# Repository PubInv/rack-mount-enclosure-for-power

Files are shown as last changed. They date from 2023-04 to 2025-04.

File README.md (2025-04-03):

# OEDCS
Oxygen Engine Digital Control System, enclosure for.

## As of 2024 the Enclosure has Evolved to a 3U rack mount
Simplified view of enclosure before connector and other holes added.


Exploded view of enclosure parts and the "Plant Panel" too


## Notes on BIG Enclosure Unit Fabrication of Spring 2023
* Serial number 1  AKA the Austin Unit.
LAN TYPE: SEEEDS STUDIO W5200
MAC Address: FE:ED:1B:70:08:77  
See images in folder at: https://github.com/PubInv/NASA-COG/tree/develop/docs/OEDCS_June_2023_Version_0.1/Photos
This is the Control V1.0 board. Taken out of service at Austin on about ?20240215?  
Control V1.1 SN 09 installed on 20240220. See its MAC below.

* Serial number 2  
  
LAN TYPE: ????
MAC Address: FE:ED:10:69:73:70  
This is the Control V1.0 board. Taken out of service at AmOx on about 20240220  
Control V1.1 SN 12 installed on 20240220. See its MAC below

* Stage II controler  
  
LAN TYPE: ????
MAC Address: FE:ED:14:71:02:77  
ID = 1361064480,1313945940,842021169,959459378

* Serial Number 9  
LAN TYPE: ARDUINO  
MAC Address: FE:ED:1D:70:05:6D
Control V1.1 SN 09 installed on OEDCS SN1 about ?20240215? 

* Serial Number 10  
LAN TYPE: ARDUINO  
MAC Address: FE:ED:12:71:06:65
Control V1.1 in Austin as of about Feb 2024.

* Serial Number 11 Formerly the Mockup Of Maryville
LAN TYPE: SEEEDS STUDIO W5200
  
MAC Address: FE:ED:16:6B:72:67

* Serial Number 12
LAN TYPE: ARDUINO  
MAC Address: FE:ED:17:73:0E:69
Located at AmOx as of about 20240220 in OEDCS SN2.

* Serial Number 13  
LAN TYPE: ARDUINO 
MAC Address: FE:ED:1A:71:09:7F
Control V1.1 in Oklahoa City as of about ?January 2024.?

## Mechanical Files

* The "frontpanel" folder has FreeCAD drawing which generate the DXF and other files for fabrication of the frontpanel, bottompanel and rear panel.
* The "enclosure" folder has an OpenSCAD drawing of the Unit 1 enclosure. With in the folder is a folder "FreeCADAssy" which has a FreeCAD drawing using the A2plus work bench and duplicates roughly the Unit 1 assembly but which has the Unit 2 frontpanel, bottompanel and rear panel files.

## Front Panel and Enclosure Folders  Unit 2
Place holder for July-August 2023 Begin Construction of Unit 2. 

* Fabrication of Version 2 unit Frontpanel, Bottompanel and Rearpanel not by hand in house. ** DONE!**  
* The Frontpanel Version 2 has enlarged AC receiptical opehnings and will require reciptical cover plates.  **DONE!**  

## Front Panel and Enclosure Folders  Unit 1
A March 2023 enclosure for prototyping, proof of concept for the COG controller. 
This prototype has:
* A programmable power supply (Voltage and current). Power Electrinics, TF800K12A. URL: https://slpower.com/downloads-and-tech-support
* Solid state relays for switching AC power to preheaters. Sparkfun # COM-13015. URL: https://www.sparkfun.com/products/13015  
* Power and PWM control for fans to force air into the COG
* Air Temperature: Adafruit MAX31850 amplifier assemblies. Adafruit Product ID: 1727. URL: https://www.adafruit.com/product/1727
* Air flow rate sensors  NOT MOUNTED
* An Arduino Due for system control.
Navigate into the folders to see more.

Overhead view of Unit 1 wiring as of June - July 2023

https://user-images.githubusercontent.com/5836181/250552512-68546480-32a5-4593-8a75-600ff2462f9f.png

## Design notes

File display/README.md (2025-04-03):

# 3U Enclosure, Display, 
Enclosure for an I2C OLED 2.4" Display and a Rotary Encoder 

## Mechanical Files
File name: OLED_2.4inchHiLetGo.FCStd


### Drawings for LCD, I2C
2.4" OLED Made scaled model from image. Used FreeCAD.


### Drawings for Rotary Encoder with Switch assembly
3D file from: https://grabcad.com/library/rotary-encoder-arduino-daughter-board-1


## Notes on Unit Fabrication
The horizontal hole spacing is same as the 3U rack mount enclosure. I began thinking it might surface mount but think it improble.

## Notes

## Firmware Files
Folder Due_BOOTUP_OLED containes Arduino IDE code for a Due which workes with an OLED on the I2C zero port, pins D20 and D21.

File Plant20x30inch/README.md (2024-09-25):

# Plant Assembly 



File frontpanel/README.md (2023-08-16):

# Frontpanel
An aluminum plate on which the NASA-COG control system electrical intefaces are mounted from, and presented to the controlled elements.
This front panel was later mounted to an enclosure defined in the enclosure folder.

## Details
Developed in FreeCAD
One FreeCAD drawing defins the **Frontpanel**, **Rearpanel** and **Bottompanel**. There is a drawing representing two DIN rails that may be mounted on the bottom panel.
Images of many parts to be mounted on the front panel are scaled and place in a group. This group can be displayed on the front panel to check the design and convey the resulting device.

## Second Front Panel Fabrication Notes
Fabrication of a Second controler beginning late July 2023.
Version 2 front panel.
FreeCAD view


Fabrication drawing for front panel Version 2.0 of 20230731


## Parts List Second Controller (Partial)
| Quantity 	| Description 	| Manufacturer 	| Man Part Number 	| Distributor 	| Distributor Part Number 	| Drawing 	| Cost Each 	|
|---	|---	|---	|---	|---	|---	|---	|---	|
| 1 	| frontpanel-PartFrontPanel2frontpanel2.dxf 	| PublicInvention 	| TBD 	| NA 	| NA 	| [frontpanel-PartFrontPanel2frontpanel2.dxf](frontpanel-PartFrontPanel2frontpanel2.dxf) 	| 	|

<hr> 

## First Front Panel Fabrication Notes
Fabrication drawing for front panel of 20230324


## Parts List (Partial)

| Quantity | Description | Manufacturer | Man Part Number | Distributor | Distributor Part Number | Drawing | Cost Each |
|---|---|---|---|---|---|---|---|
| 1 | frontpanel_Rev1_3.dxf | PublicInvention | TBD | NA | NA | [frontpanel_Rev1_3.dxf](frontpanel_Rev1_3.dxf) | |
| 3 | Panel Plate SB1 Dual | | | Powerwerx | PanelPlateSBDual | [SB1 Drawing](Parts/Mech/PanelplateSB1-SB1DuaulDimensions.pdf) | 14.99 |
| 6 | Protective Plug with Lanyard | | | Powerwerx | PLUG-SB50 | https://powerwerx.com/rigid-plug-cap-lanyard-sb50 | 4.49 |
| 3 | Circuit Breaker | Carling Technologies | AA1-B0-34-615 -5D1-C | Granger | 10C591 | [Breaker Drawing](Parts/Mech/Breaker_10C588_1.pdf) | 14.77 |
| 3 | GFI Receptical | | | Harbor Freight | 57958 | https://www.harborfreight.com/15-amp-125v-self-test-gfci-duplex-outlet-57958.html | 9.99 |
| 1 | DB25 Panel Mount, FanControllerBareBoardPCB  | PublicInvention | TBD | | | [FanControllerBareBoardPCB.jpg](../develop/elec/FanControllerBareBoardPCB.jpg) | |
| 1 | DB9 Panel Mount, I2C interface | PublicInvention | TBD | | | | |
| 1 | ground bar | GE | TGK12CP | Lowes | 105748 | https://www.lowes.com/pd/GE-1-in-Ground-Bar-Kit/1001535 | $8.98 |
| 1 | Jack Panel for Thermocouple 1x12 | Omega | MJP1-12-BLANK | Omega | MJP1-12-BLANK | [Jack Panel Drawing](Parts/Mech/mpj-j-f-thermocouple/JackPanel_MJP.pdf) | $26.76 |
| 1 | Snap Strip for Thermocouple  1x12 | Omega | MMS-12 | Omega | MSS-12 | [SnapStrip Drawing](Parts/Mech/MSS_Series.pdf) | 12.34 |
| 3 | Miniature Thermocouple Panel Jack Connectors | Omega | MPJ-K-F | Omega | MPJ-K-F | [SnapStrip Drawing](Parts/Mech/MSS_Series.pdf) | $4.26 |
| 24 | M5-8mm pan head screw | | | Amazon | | https://www.amazon.com/M5-0-8-Button-Socket-Stainless-Quantity/dp/B084MMND2L/ref=asc_df_B084MMND2L | $.0899 |
| 24 | 5mm T Nut Sliding 10mmx6mm | | | Amazon | | https://www.amazon.com/Fastener-Nickel-Plated-Sliding-Aluminum-Profile/dp/B086MKNYDS/ref=sr_1_1_sspa | $0.053 |

### Some deviations of note:
I drilled and tapped the holes for mounting the GFI receipticals for 6-32 screw holes and screwed the GFI from the rear with shortened screws. The protuding ends of these screews are a minor hazard for scratching flesh.  
I drilled and tapped the screw holes for 10-32 for mounting the ground bar.
I attached a single teathered connector cap for the Anderson connector with a plastic cable clamp to a near by screw mounting the circuit breaker.  

?April 2023? Robert relocated the ground lug terminal strip inside the cabnet. Lee believes new holes had to be drilled.

## Older FreeCAD screen capture showing images of some of the parts behind the "frontpanel".  
These drawings and ideas lead up to the first fabricated front panel and differ from it.  
Images as of 20230317 2107 EDT




### Cautions
There appears to be an error on the holes for the Anderson front panel connector mount. (20230326 FLE, Corrected before fabrication.)

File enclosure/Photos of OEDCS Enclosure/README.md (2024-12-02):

# 3U OEDCS Assembled
Photos of the October 2024 build of five OEDCS final assemblies.  
Front panels are REV1 which required extensive nibbeling of the SB50 flange.  

<a
href="FrontPanel.JPG">
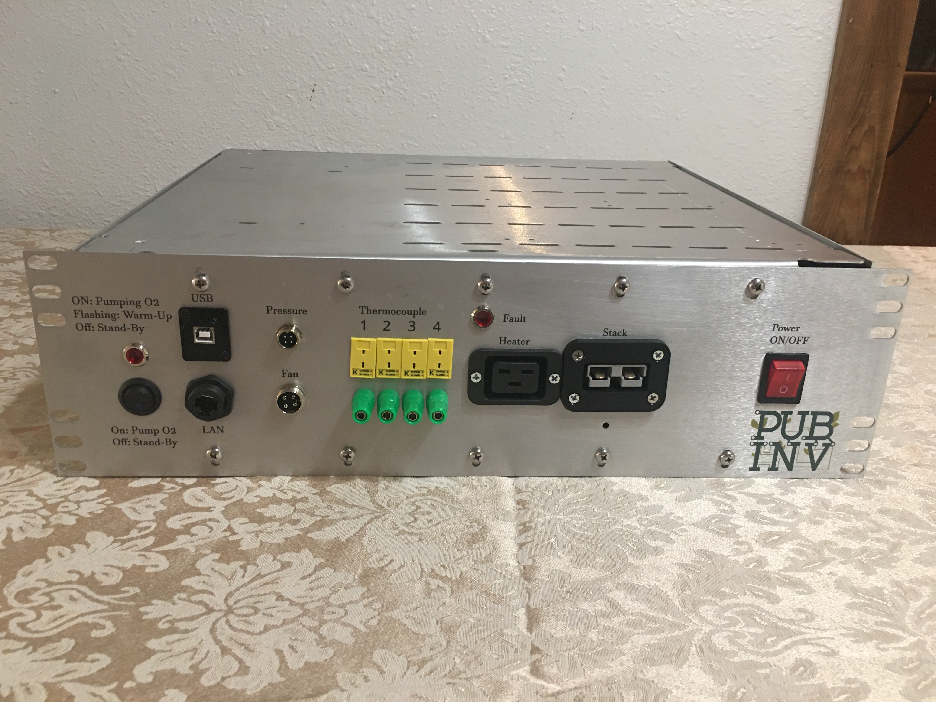
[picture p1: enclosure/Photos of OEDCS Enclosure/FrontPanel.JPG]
  
Front view as assemblied. Click to enlarge </a>

<a
href="Back.JPGg">
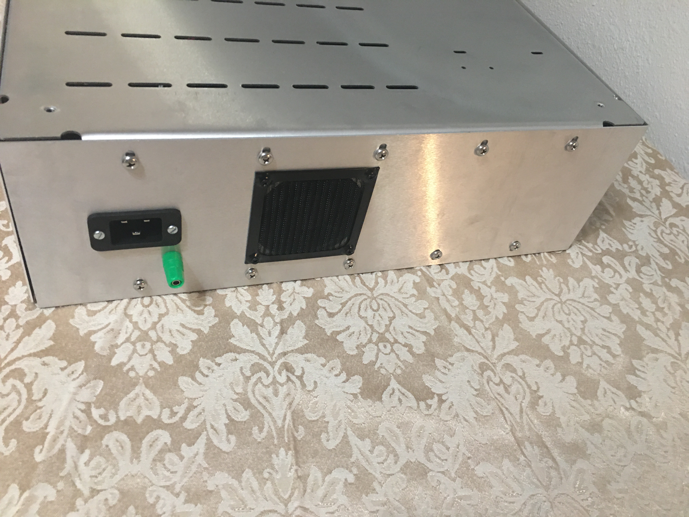
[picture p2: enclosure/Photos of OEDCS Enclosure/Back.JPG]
Back.JPGg
  
Back view as assemblied. Click to enlarge </a>

<a
href="CablesInPlace.JPG">
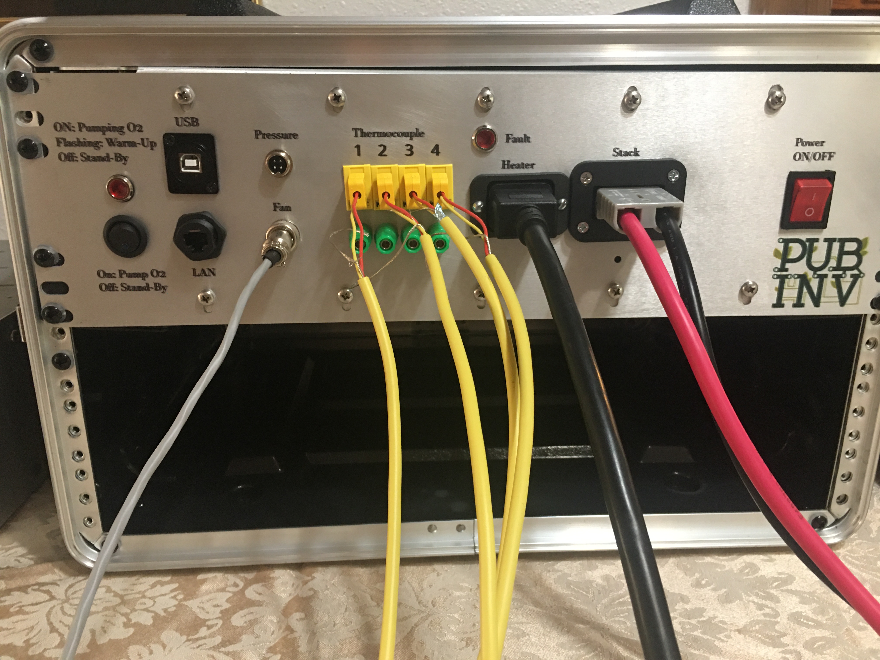
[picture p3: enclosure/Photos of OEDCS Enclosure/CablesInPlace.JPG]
CablesInPlace.JPGG
  
Front view wtih cables. Click to enlarge </a>

<a
href="FrontFromTop.JPG">
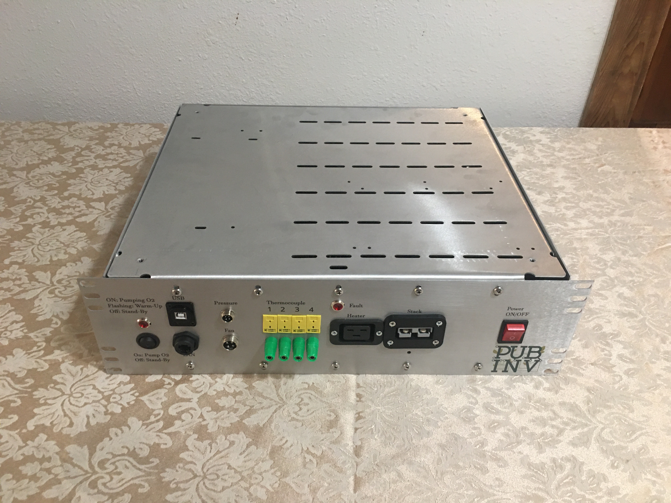
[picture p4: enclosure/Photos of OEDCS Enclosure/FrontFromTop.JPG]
  
Front from top view as assemblied. Click to enlarge </a>

<a
href="Oblique.JPG">
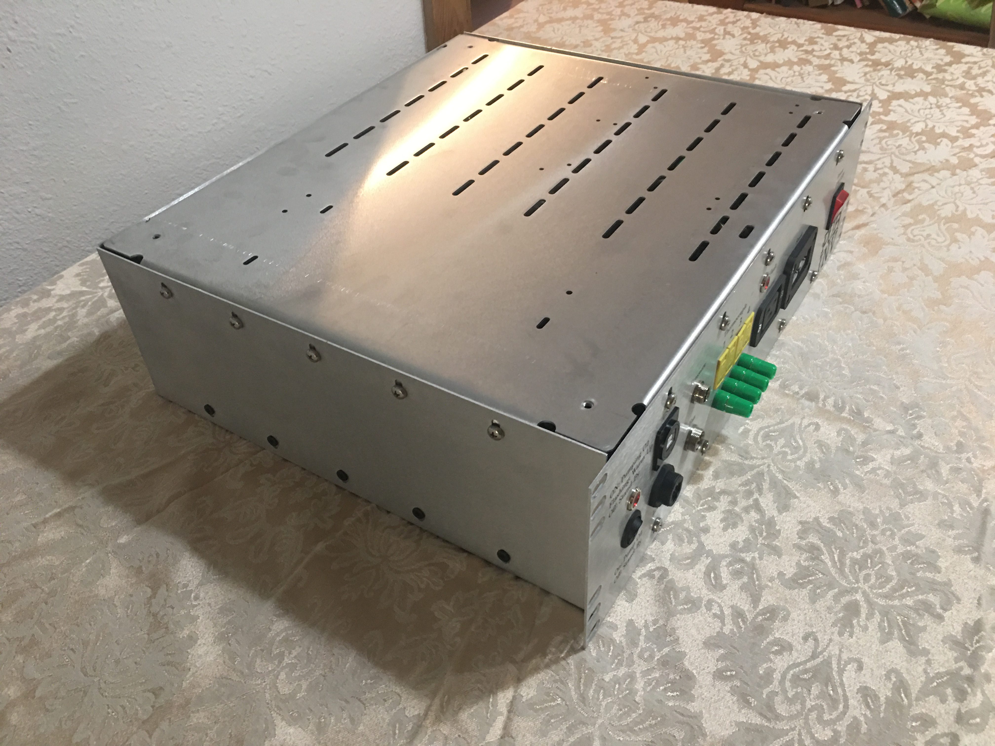
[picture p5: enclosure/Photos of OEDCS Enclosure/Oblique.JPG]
  
Oblique view as assemblied. Click to enlarge </a>

<a
href="Top.JPG">
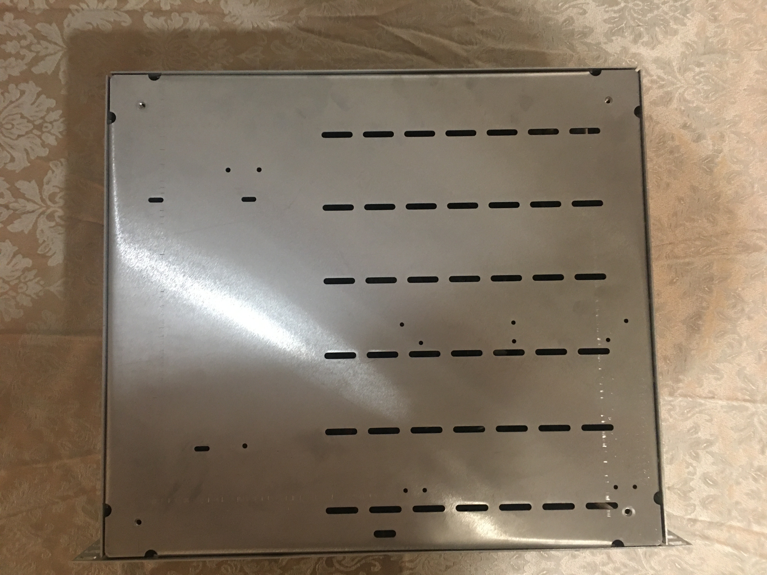
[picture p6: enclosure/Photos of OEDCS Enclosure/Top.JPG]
  
Top view as assemblied. Click to enlarge </a>

<a
href="TopOblique.JPG">
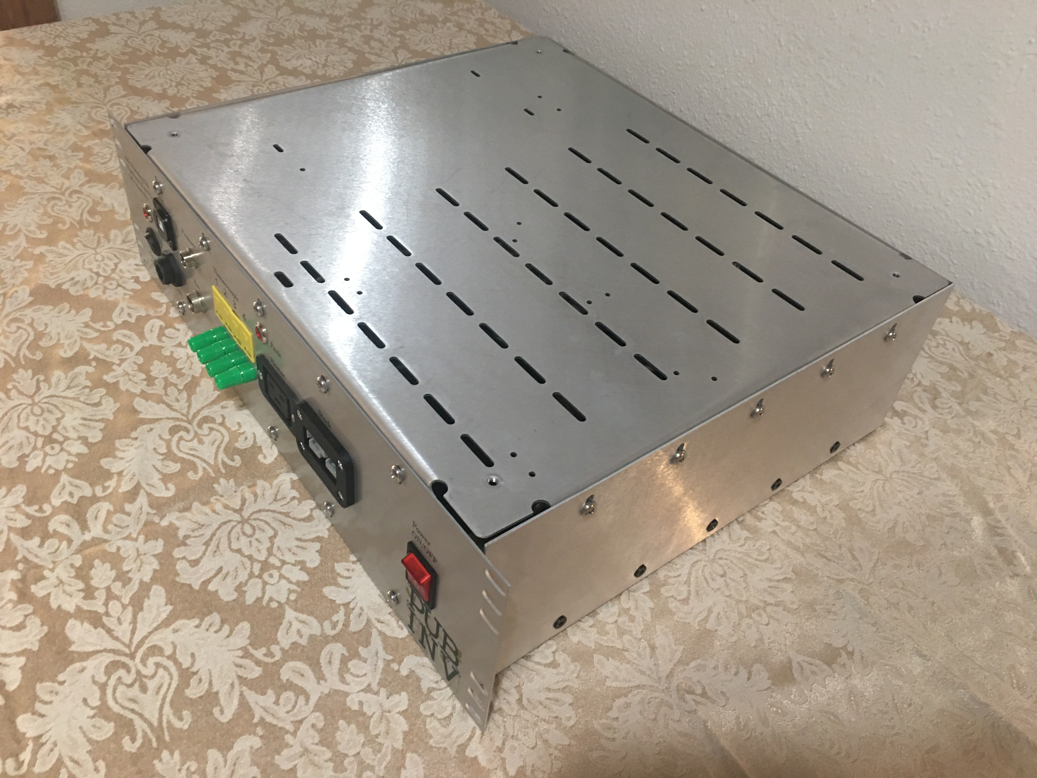
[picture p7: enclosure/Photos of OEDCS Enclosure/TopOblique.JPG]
  
Top oblique view as assemblied. Click to enlarge </a>

<a
href="PowerCloseUp.JPG">
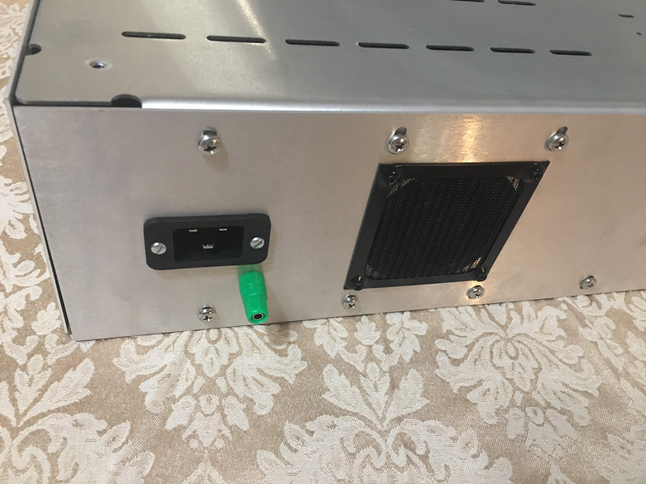
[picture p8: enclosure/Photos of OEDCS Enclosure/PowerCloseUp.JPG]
  
Power connections detail view as assemblied. Click to enlarge </a>

<a
href="OEDCSInRack.JPG">
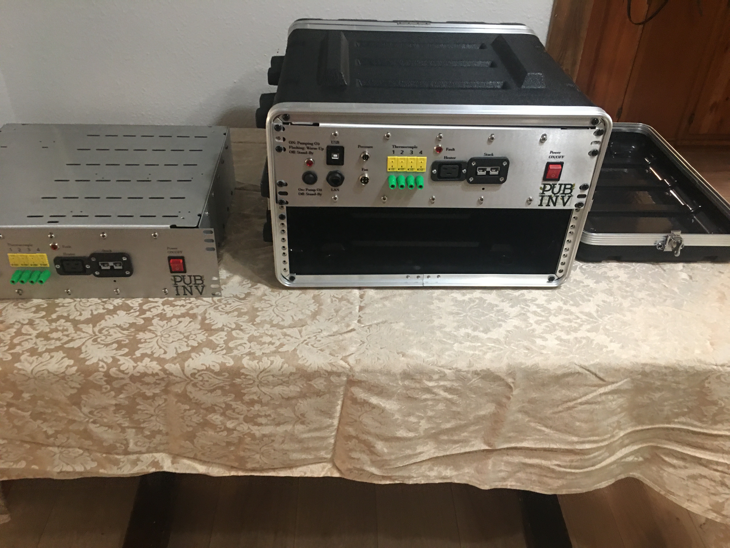
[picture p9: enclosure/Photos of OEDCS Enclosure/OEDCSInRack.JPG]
  
OEDCS in the travel rack. Click to enlarge </a>

<a
href="OEDCSShippingAndRack.JPG">
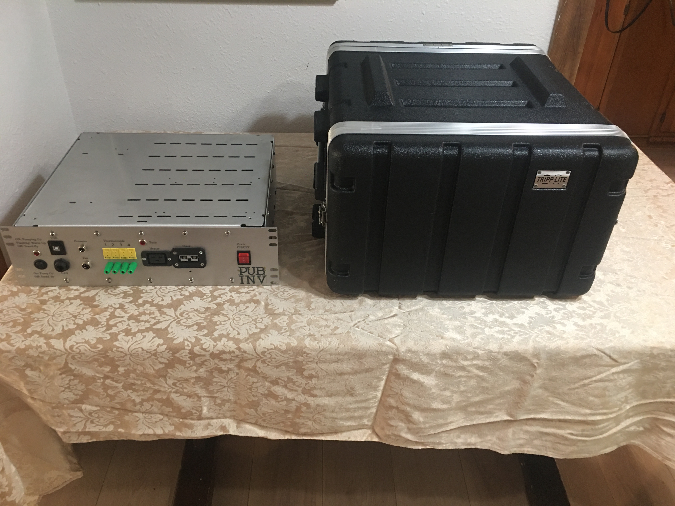
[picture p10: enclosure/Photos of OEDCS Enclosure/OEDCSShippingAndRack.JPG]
  
Overview of OEDCS in the travel rack wtih cover on. Click to enlarge </a>

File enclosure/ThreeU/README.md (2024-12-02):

# Files
A FreeCAD paremetric drawing for a 3U Chassis and Front Panel. STL files for same.

## Chassis and Front Panel Blank
_Isometric view of the ThreeU_Chassis.FCStd parts as of 20240628_


_Isometric view of the assembly as of 20240617_


<a
href="3U_OEDCS_Oblique.JPG">
  
Oblique view as assemblied. Click to enlarge </a>

<a
href="3U_OEDCS_FrontView.jpg">
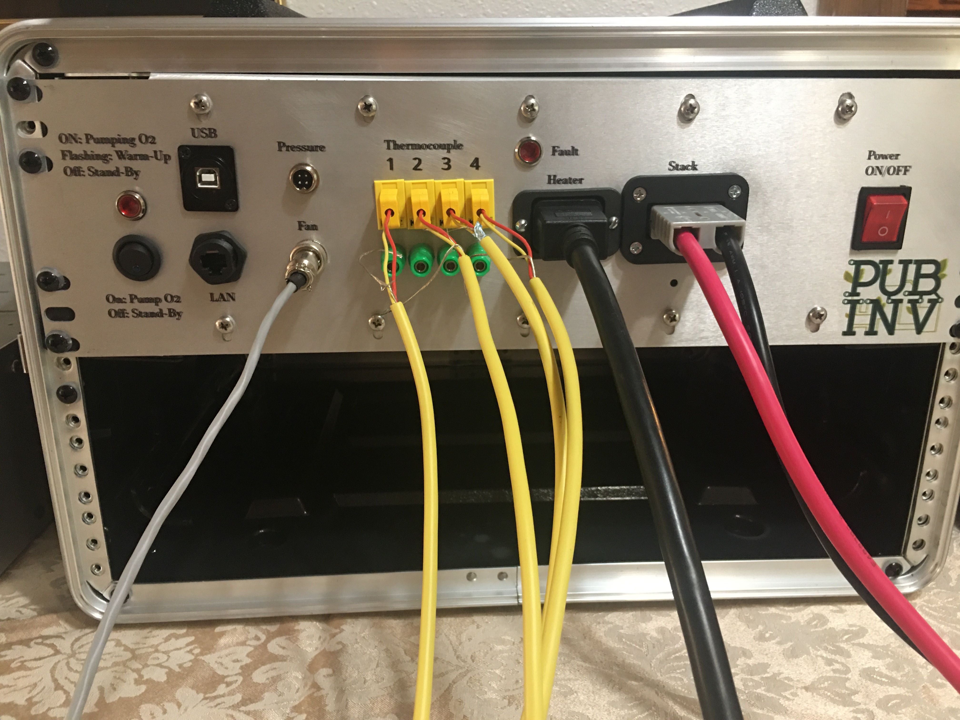
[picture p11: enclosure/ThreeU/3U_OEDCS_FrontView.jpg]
  
Front view as assemblied. Click to enlarge </a>

## Parts List
The parts list of the 3U OEDCS as per our goal to build about 5 units.
(Use the A2Plus parts list feature to generate a Parts List in the assembly. Select the cells not empty and copy. Past into https://tablesgenerator.com/markdown_tables)

| POS 	| QTY 	| IDENTNO 	| DESCRIPTION 	| SUPPLIER 	| SUPP.IDENTNO 	| SUPP.DESCRIPTION 	| (FILENAME) 	|
|-----	|-----	|---	|---	|---	|---	|---	|---	|
| 1 	| 1 	| * 	| * 	| * 	| * 	| * 	| TF800.STEP 	|
| 2 	| 1 	| * 	| * 	| * 	| * 	| * 	| Control_v1FcuEdgeCuts.step 	|
| 3 	| 1 	| * 	| * 	| * 	| * 	| * 	| EthernetShieldUNO.step 	|
| 4 	| 1 	| * 	| * 	| * 	| * 	| * 	| 2D3D 538 B.stp 	|
| 5 	| 1 	| * 	| * 	| * 	| * 	| * 	| Solid State Relay Heat Sink, SSR-40DD.STEP 	|
| 6 	| 1 	| * 	| * 	| * 	| * 	| * 	| ALIM MEAN WELL MDR-10-12.STEP 	|
| 7 	| 1 	| * 	| * 	| * 	| * 	| * 	| ALIM MEAN WELL MDR-100-24.STEP 	|
| 8 	| 1 	| * 	| * 	| * 	| * 	| * 	| M12BulkHeadToBlunt.FCStd 	|
| 9 	| 1 	| * 	| * 	| * 	| * 	| * 	| SBS50 03-09-STEP.stp 	|
| 10  	| 1 	| * 	| * 	| * 	| * 	| * 	| PanelPlate_SB-PartSB2BodySB2.step 	|
| 11  	| 3 	| * 	| * 	| * 	| * 	| * 	| MPJ-K-F.STEP 	|
| 12  	| 1 	| * 	| * 	| * 	| * 	| * 	| e_0100.6436a002.step 	|
| 13  	| 1 	| * 	| * 	| * 	| * 	| * 	| Bigtreetech Mini12864 V1.0-3D.step 	|
| 14  	| 1 	| * 	| * 	| * 	| * 	| * 	| Mini_prusa_LCD_Mount_Top.step 	|
| 15  	| 1 	| * 	| * 	| * 	| * 	| * 	| ThreeU_Chassis.FCStd 	|
| 16  	| 1 	| * 	| * 	| * 	| * 	| * 	| 8961K89_Steel DIN 3 Rail.STEP 	|

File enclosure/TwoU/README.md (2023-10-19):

# Files
A FreeCAD paremetric drawing for a 2U Chassis and Front Panel. STL files for same.

## Chassis and Front Panel Blank

_Isometric view as of 20231018_

## In An Assembly



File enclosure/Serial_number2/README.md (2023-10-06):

# Serial Number 2 OEDCS Enclosure
Information capturing the build of Serial_number2 OEDCS 

## Details

## Second Enclosure Fabrication Notes and Photos
### CAD drawings. 
Isometric view of FreeCad assembly drawing showing the Ethernet, Controller V1 and Due assembly off to the side.
> 

Serial number 2, Assembly on 20230914




### Parts
Enclosure 2 parts and assembly stuff  
> 

Front and bottom panels  
> 

Bottom and rear panel  
> 

### Some deviations of note during assembly
We had to......
Lawrence made modifications to the DXF files for rear panel holes
and may include the following
> On 08/14/2023 5:56 PM EDT Lawrence Kincheloe <lokimail@gmail.com> wrote:
> I would also like to add a USB and Ethernet jack to the back as well.
> Both require a 30 mm hole. 
> https://www.adafruit.com/product/4212
> https://www.adafruit.com/product/4130
> Something missing from this diagram is cutouts for the fans for the power supplies and SSR. These WILL need active cooling and we will need to account for air flow from the back to the side panels 

## Parts List (Partial)
*stuff here in a table*

### Other:
This does not include the ...

### Wiring of Assemblies In Enclosure

*stuff here such as the asembly of the DUE, Controller V1, and Ethernet cards*
The Due and ethernet cards mount with the Controler V1 card something like this:
Perspective view showing the ethernet card above the Controler V1 card  
>   

Top view showing the ethernet card above the Controler V1 card  
>   

Bottom view showing the Due card above the Controler V1 card  
> 

Side view showing the ethernet card above the Controler V1 card and the Due below
> 

Actual Control v1 with Ethernet and Due  
<a
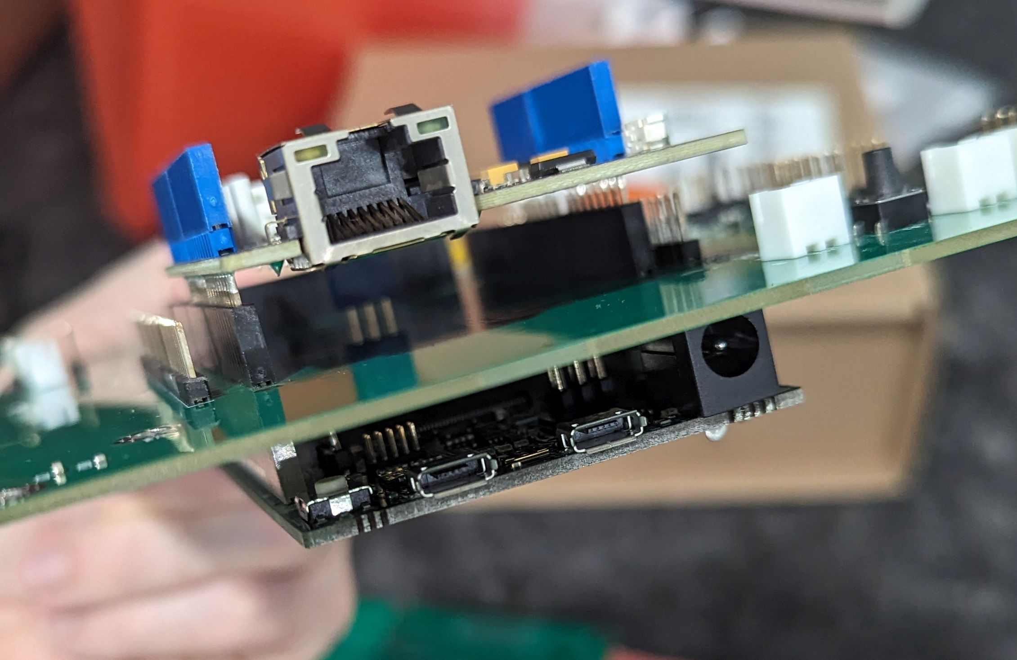
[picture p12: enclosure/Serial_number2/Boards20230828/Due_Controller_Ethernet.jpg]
href="Boards20230828/Due_Controller_Ethernet.jpg">   
***Due_Controller_Ethernet.jpg***
</a>

Controller thermocouple wiring detail  
<a
href="https://user-images.githubusercontent.com/5054116/268123079-14d45110-6290-4cd9-9399-6f682203b03e.jpg"> Thermocouple wiring detail image  
***Thermocouple wiring detail***
</a>

### Cautions
None.

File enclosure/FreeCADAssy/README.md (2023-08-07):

# Enclosure Drawings

## FreeCAD Drawing of Enclosure Unit 2



Note the 20x20mm extrustions are approximated by square tubes.

## Parts List, Unit 2
| **Item** | **Quantity** | **Part Number** | **Description** | **Cost** | **Note** |
|---|---|---|---|---|---|
| 1 | 4 | | 20x20x240mm Extrusion  | | Sets height when combined with 40mm |
| 2 | 4 | | 20x20x460mm Extrusion  | | Sets length when combined with 3.15mm |
| 3 | 4 | | 20x20x400mm Extrustion | | Sets width when combined with 40mm |
| 4 | 2 | | 20x20x420mm Extrusion  | | Possible shelf support. |
| 5 | 1 | frontpanel-PartFrontPanel2frontpanel2.dxf | Front panel V2 DXF | | |
| 6 | 1 | frontpanel-PartBottomPlateV2.oBodyBottomPlateV2.dxf | Bottom panel V2 DXF | | |
| 7 | 1 | RearPanel3.dxf | Rear panel for V2 DXF  | | |
| 8 | | | | | |
| 9 | | | | | |

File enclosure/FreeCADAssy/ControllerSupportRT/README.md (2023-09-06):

# Files Description
These files are for a bracket to support the Controller V1 PCB to the front panel



With Controler V1 PWA (Printed Wiring Assembly).


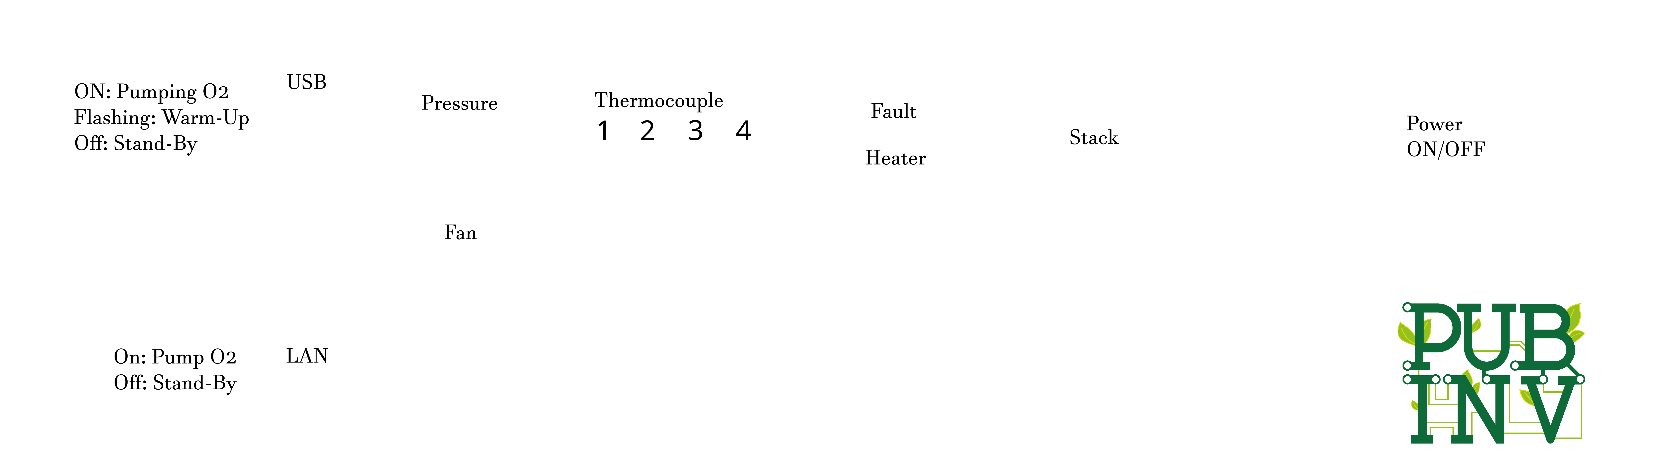
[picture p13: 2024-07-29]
enclosure/ThreeU/ThreeU_Chassis-BodyFrontPanelWithHolesPocketFrontPanelHoles Labels.png

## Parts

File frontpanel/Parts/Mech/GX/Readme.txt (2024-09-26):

GX12 file from: https://grabcad.com/library/gx12-4-1

GX16-4 from: https://grabcad.com/library/gx-16-connector-4-pins-1

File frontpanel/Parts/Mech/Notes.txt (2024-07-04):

Origin of models:

https://grabcad.com/library/extrusion-profile-20x20mm-1

https://grabcad.com/library/2020-extrusion-corner-bracket-1

https://grabcad.com/library/aluminium-corner-bracket-2028-1

https://grabcad.com/library/mpj-j-f-thermocouple-connector-omega-1

Fan DC Fan Model v5.step

https://grabcad.com/library/80mm-fan--1

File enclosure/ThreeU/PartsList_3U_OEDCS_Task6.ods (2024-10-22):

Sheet: Task6_Deliverables
Parts list for the Task 6 Deliverables
Each, A rack mounted 3U OEDCS and O2 Purity Monitor System
3U_OEDCS and 02 Purity in Rack
Three U tall rack mount OEDCS
O2 Purity
Rack Mount
 |  |  |  |  |  | Total= | Err:509
Reference | Value | Description | Distributor_1 | Distributor_PN | Quantity | Cost_Each | Cost_Ext | Note
3U_OEDCS | 3U_OEDCS | 3U_OEDCS | PublicInvention | 3U_OEDCS | 1 | $3,000,726.75 | $3,000,726.75 | Built with ControlV1.1
O2 Purity | O2 Purity | O2 Purity | PublicInvention | O2 Purity | 1 | $2,000,000.00 | $2,000,000.00
Rack Mount | Rack Mount Music | Rack Mount Music | Digikey | foo | 1 | $1,000,000.00 | $1,000,000.00
RailMount | RailMount | ??? | ??? | boogar | 1 | $1,000,000.00 | $1,000,000.00
SCR99 | SCR_5MMx6MM | this and that | ??? | boogar | 99 | $1,000,000.00 | $99,000,000.00
PlantPanel | 3U_PlantPanel_V1 | 3U_PlantPanel_V1 | PublicInvention | ThreeU_Chassis_BodyPlantPanel20240924_1929.step | 1 | 26.1 | $26.10 | SendCutSend ORDER #TBD
GX12-4 1 | GX12-4 | GX12 4 Pins Panel Metal Mount Circular Metal Aviation Connector | Amazon | GX12 4 Pins Panel Metal Mount Circular Metal Aviation Connector | 1 | $1.80 | $1.80 | https://www.amazon.com/dp/B089YTG1SX
GX16-4 1 | GX16-4 | GX16 4 Pins Panel Metal Mount Circular Metal Aviation Connector | Amazon | GX16 4 Pins Panel Metal Mount Circular Metal Aviation Connector | 1 | $1.20 | $1.20 | https://www.amazon.com/dp/B07D3DC1PD
KS 1, KS 2, KS 3, KS 4 | K_Socket | K Type Panel Mount Thermocouple Female Mini Socket | Amazon | K Type Panel Mount Thermocouple Female Mini Socket | 4 | $2.93 | $11.72 | https://www.amazon.com/dp/B0CZ311LSZ
BN 1, BN2, BN3, BN4, BN5 | Post Banana Plug Jack Green | Terminal Binding Post Amplifier Terminal Connector Banana Plug Jack Speaker Green | Amazon | Terminal Binding Post Amplifier Terminal Connector Banana Plug Jack Speaker Green | 5 | $2.47 | $12.36 | https://www.amazon.com/dp/B09MSXW98N
PNL_MNT1 | SB50PNLMNTSINGLE | Mounting Panel with Dust Cover Compatible with Anderson SB50 | Amazon | 50A Plug Mounting Panel with Dust Cover Compatible with Anderson SB50 | 1 | $5.95 | $5.95 | https://www.amazon.com/dp/B0CHMNNNH9
AC 3 | C20 | C20 with Mounting Holes Adapter,Toptekits C20 Panel Mount Plug Adapter AC 250V 16A 3 Pins IEC Inlet | Amazon | C20 with Mounting Holes Adapter,Toptekits C20 Panel Mount Plug Adapter AC 250V 16A 3 Pins IEC Inlet | 1 | $4.00 | $4.00 | https://www.amazon.com/dp/B0B3VNM3CP
foo | foobar | this and that | PublicInvention | boogar | 1 | $1,000,000.00 | $1,000,000.00

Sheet: 3U_OEDCS
3U_OEDCS
Three U tall rack mount OEDCS
The Controll assembly, 3U enclosure, Stack supply, 12V supply, 24 Supply, Battery, DINRail, DINRailConnectors, wiring, and ????
 |  |  |  |  |  | Total= | $3,000,726.75
Reference | Value | Description | Distributor_1 | Distributor_PN | Quantity | Cost_Each | Cost_Ext | Note
3UChassis18x15 | BodyChassis_18x15_V1 | BodyChassis_18x15 Version 1 | PublicInvention | ThreeU_Chassis_PartChassisBodyChassis_18x15_20240701_1059.step | 2 | $51.38 | $102.76 | SendCutSend ORDER #S581V200
Front | 3U_FrontPanel_V1 | 3U Front Panel with holes Version 1 | PublicInvention | ThreeU_Chassis_BodyFrontPanelWithHoles20240708_1444.step | 1 | $27.23 | $27.23 | SendCutSend ORDER #S581V200
Rear | 3U_RearPanel_V1 | 3U Rear Panel with holes Version 1 | PublicInvention | ThreeU_Chassis_BodyRearPanelWithHoles20240705_1543.step | 1 | $16.35 | $16.35 | SendCutSend ORDER #S581V200
Side | 3U_SidePanel_V1 | 3U Side Panel with holes Version 1 | PublicInvention | ThreeU_Chassis_BodySidePanel20240630_1804.step | 2 | $9.39 | $18.78 | SendCutSend ORDER #S581V200
Screws | PanHead_Philips5mmx8mm | ??? | ??? | ??? | 44 | $0.50 | $22.00 | ???
 |  |  |  |  | Enc Subtotal= | $104.85
PWA1 | CntrlAssyV1.1 | Control PWA OEDCS Version 1.1 | PublicInvention | CntrlAssyV1.1 | 1 | $46.00 | $46.00 | JLCPCB W202310181558446
STACKSUPPLY1 | TF800A12K | Programable Voltage Current Supply 12V 60A | Power Electronics | TF800A12K | 1 | $333.50 | $333.50 | DigitKey: 271-3027-ND
+12V_5A_Rail_Supply | +12V_5A_Rail_Supply | MEAN WELL MDR-60-12 AC to DC DIN-Rail Power Supply 12V 5 Amp 60W | Amazon | MEAN-WELL-MDR-60-12-DIN-Rail-Supply | 1 | $20.42 | $20.42 | https://www.amazon.com/MEAN-WELL-MDR-60-12-DIN-Rail-Supply/dp/B00DECZ7WC
+24V_5A_Rail_Supply | +24V_1.7A_Rail_Supply | Mean Well MDR-40-24 Power Supply, DIN-Rail, 24 Volt, 1.7 Amp, 40.8 Watt, 3.9" x 1.6" x 3.5" Size | Amazon | Mean Well MDR-40-24 Power Supply | 1 | $21.69 | $21.69 | https://www.amazon.com/Mean-MDR-40-24-Power-Supply-DIN-Rail/dp/B005T6INFE
Battery1 | Battery +12V 7.2aH | Mighty Max Battery ml7-12 - 12 Volt 7.2 ah SLA Battery Brand Produc | Amazon | Mighty Max Battery ml7-12 - 12 Volt 7.2 ah SLA Battery Brand Produc | 1 | $19.99 | $19.99 | https://www.amazon.com/dp/B00K8V30D0
DIN_Rail1 | DIN Rail 12" | Aluminum DIN Rails, 12 Inches Long | Amazon | Aluminum DIN Rails, 12 Inches Long, 35mm Wide, 7.5mm High, Top Hat Slotted DIN Rail | 1 | $1.60 | $1.60 | https://www.amazon.com/dp/B0CDPSG9GY
PNL_LED1 | PNL_LED_12MM_GREEN | ???? | Amazon | ??? | 1 | $1,000,000.00 | $1,000,000.00 | ???
PNL_SW 1 | PNL_SW_BLUELED_SPST | Round Blue Toggle LED Rocker Switch On-Off Control SPST 3Pins | Amazon | Round Blue Toggle LED Rocker Switch On-Off Control SPST 3Pins | 1 | $1.10 | $1.10 | https://www.amazon.com/dp/B08TBZ23C1
USB_THROUGH 1 | Panel Mount USB B to A | Panel Mount USB B to A | Amazon | USB B to A Panel Mount | 1 | $13.99 | $13.99 | https://www.amazon.com/dp/B0CLL51XXV
RJ45_THROUGH 1 | Panel Mount Feedthrouth RJ45 | Panel Mounting Shielded RJ45 Waterproof Cat5/5e/6 8P8C Connector | Amazon | Panel Mounting Shielded RJ45 Waterproof Cat5/5e/6 8P8C Connector | 1 | $4.60 | $4.60 | https://www.amazon.com/dp/B07KSSV8LD
GX12-4 1 | GX12-4 | GX12 4 Pins Panel Metal Mount Circular Metal Aviation Connector | Amazon | GX12 4 Pins Panel Metal Mount Circular Metal Aviation Connector | 1 | $1.80 | $1.80 | https://www.amazon.com/dp/B089YTG1SX
GX16-4 1 | GX16-4 | GX16 4 Pins Panel Metal Mount Circular Metal Aviation Connector | Amazon | GX16 4 Pins Panel Metal Mount Circular Metal Aviation Connector | 1 | $1.20 | $1.20 | https://www.amazon.com/dp/B07D3DC1PD
KS 1, KS 2, KS 3, KS 4 | K_Socket | K Type Panel Mount Thermocouple Female Mini Socket | Amazon | K Type Panel Mount Thermocouple Female Mini Socket | 4 | $2.93 | $11.72 | https://www.amazon.com/dp/B0CZ311LSZ
BN 1, BN2, BN3, BN4, BN5 | Post Banana Plug Jack Green | Terminal Binding Post Amplifier Terminal Connector Banana Plug Jack Speaker Green | Amazon | Terminal Binding Post Amplifier Terminal Connector Banana Plug Jack Speaker Green | 5 | $2.47 | $12.36 | https://www.amazon.com/dp/B09MSXW98N
PNL_LED2 | PNL_LED_12MM_RED | 12mm 3V-4.5V-5V-6V-7.5V-9VDC LED Metal Indicator Light Waterproof Signal Lamp Pilot | Amazon | 12mm 3V-4.5V-5V-6V-7.5V-9VDC LED Metal Indicator Light Waterproof Signal Lamp Pilot | 1 | $2.25 | $2.25 | https://www.amazon.com/dp/B09L7WPHBZ
AC 1 | C19 | C19 Panel Mount Plug Socket Adapter AC 250V 16A Inlet Module Plug Power Connector Socket Staight | Amazon | C19 Panel Mount Plug Socket Adapter AC 250V 16A Inlet Module Plug Power Connector Socket Staight | 1 | $4.00 | $4.00 | https://www.amazon.com/dp/B0B3VR24JH
PNL_MNT1 | SB50PNLMNTSINGLE | Mounting Panel with Dust Cover Compatible with Anderson SB50 | Amazon | 50A Plug Mounting Panel with Dust Cover Compatible with Anderson SB50 | 1 | $5.95 | $5.95 | https://www.amazon.com/dp/B0CHMNNNH9
PNL_SW 2 | PNL_SW_AC_LIGHT | 30A 250VAC/35A 125VAC KCD2 KCD4 Rocker Switch DPST 4 Pin Red Lighted 120V Rocker Toggle Switch ON Off | Amazon | 30A 250VAC/35A 125VAC KCD2 KCD4 Rocker Switch DPST 4 Pin Red Lighted 120V Rocker Toggle Switch ON Off | 1 | $2.73 | $2.73 | https://www.amazon.com/dp/B0BB9KJDCN
AC 2 | C20 | C20 with Mounting Holes Adapter,Toptekits C20 Panel Mount Plug Adapter AC 250V 16A 3 Pins IEC Inlet | Amazon | C20 with Mounting Holes Adapter,Toptekits C20 Panel Mount Plug Adapter AC 250V 16A 3 Pins IEC Inlet | 1 | $4.00 | $4.00 | https://www.amazon.com/dp/B0B3VNM3CP
FAN_FLT 1 | FILTER_FAN_80mm | 80mm Computer Fan Filter Grills with Screws, Aluminum Frame Ultra Fine Stainelss Steel | Amazon | 80mm Computer Fan Filter | 1 | $3.25 | $3.25 | https://www.amazon.com/dp/B07LG41F1K
FAN 1 | FAN 80 MM | ???? |  |  | 1 | $1,000,000.00 | $1,000,000.00
??? | ??? | Scheider SSR | Mouser? | SSP1A125BD | 1 | $27.51 | $27.51 | https://www.digikey.com/en/products/detail/schneider-electric/SSP1A125BD/16613849
foo1 | Foo_bar | this and that | Nowhereman | foo | 1 | $1,000,000.00 | $1,000,000.00 | foo
 |  |  |  |  | SubAssy Subtotal= | $3,000,520.95
ASSY_CBL_1 | ASSY_CBL_6AWG_300mm_BLACK_RED | Assy cable 6AWG 300mm Black Red | PublicInvention | ??? | 1 |  |  | Stack Supply to SB50
last line |  |  |  |  |  |  | $0.00

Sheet: O2_PurityMonitor
O2 Purity Monitor
O2 Measurement and Logging
This that and more
 |  |  |  |  |  | Total= | $2,000,000.00
Reference | Value | Description | Distributor_1 | Distributor_PN | Quantity | Cost_Each | Cost_Ext | Note
Foo 1 | O2 thing 1 | O2 thing 1 |  |  | 1 | $1,000,000.00 | $1,000,000.00 | ORDER #TBD
Bar 1 | O2 thing 2 | O2 thing 2 |  |  | 1 | $1,000,000.00 | $1,000,000.00 | ORDER #TBD

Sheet: Controller_Assembly_V1.1
BOM generated by STF in KiCAD
CntrlAssyV1.1
Reference | Value | Footprint | Datasheet | AssemblyType | Category | Cost | DK_Datasheet_Link | DK_Detail_Page | Description | Digi-Key_PN | Distributor 1 | Distributor 1 PN | Distributor 2 | Distributor 2 PN | Family | LongLead | MPN | Manufacturer | Part Number | Status | Qty
A1 | Arduino_Due_Shield | PubInv_KiCad_PCB:Arduino_Due_Shield_Annotated | https://docs.arduino.cc/hardware/due |  |  |  |  |  |  |  |  |  |  |  |  |  |  |  |  |  | 1
D_PSU_RX1 | D_PSU_RX | TestPoint:TestPoint_Loop_D2.54mm_Drill1.5mm_Beaded | ~ | HAND |  | 0 |  |  |  |  |  |  |  |  |  |  |  |  |  |  | 1
D_PSU_RX2 | D_PSU_RX2 | TestPoint:TestPoint_Loop_D2.54mm_Drill1.5mm_Beaded | ~ | HAND |  | 0 |  |  |  |  |  |  |  |  |  |  |  |  |  |  | 1
D_PSU_TX1 | D_PSU_TX | TestPoint:TestPoint_Loop_D2.54mm_Drill1.5mm_Beaded | ~ | HAND |  | 0 |  |  |  |  |  |  |  |  |  |  |  |  |  |  | 1
D_PSU_TX2 | D_PSU_TX2 | TestPoint:TestPoint_Loop_D2.54mm_Drill1.5mm_Beaded | ~ | HAND |  | 0 |  |  |  |  |  |  |  |  |  |  |  |  |  |  | 1
R17, R30, R34, R35, R43, R51-R53, R55, R60, R63, R74, R75, R85-R87, R89, R90, R118, R120 | DNI | Resistor_SMD:R_0603_1608Metric_Pad0.98x0.95mm_HandSolder | -- mixed values -- | -- mixed values -- |  | 0 |  |  | -- mixed values -- |  |  |  |  |  |  | -- mixed values -- | -- mixed values -- | -- mixed values -- |  |  | 20
TP1, TP3, TP4, TP11, TP21 | GND | TestPoint:TestPoint_Loop_D2.54mm_Drill1.5mm_Beaded | ~ | HAND |  | NA |  |  |  |  |  |  |  |  |  |  |  |  |  |  | 5
TP2 | +12V | TestPoint:TestPoint_Loop_D2.54mm_Drill1.5mm_Beaded | ~ | HAND |  | NA |  |  |  |  |  |  |  |  |  |  |  |  |  |  | 1
TP5 | +VccMAX31850 | TestPoint:TestPoint_Loop_D2.54mm_Drill1.5mm_Beaded | ~ | HAND |  | NA |  |  |  |  |  |  |  |  |  |  |  |  |  |  | 1
TP6 | +VccMAX31850_1 | TestPoint:TestPoint_Loop_D2.54mm_Drill1.5mm_Beaded | ~ | HAND |  | NA |  |  |  |  |  |  |  |  |  |  |  |  |  |  | 1
TP7 | +VccMAX31850_2 | TestPoint:TestPoint_Loop_D2.54mm_Drill1.5mm_Beaded | ~ | HAND |  | NA |  |  |  |  |  |  |  |  |  |  |  |  |  |  | 1
TP8 | +VccMAX31850_3 | TestPoint:TestPoint_Loop_D2.54mm_Drill1.5mm_Beaded | ~ | HAND |  | NA |  |  |  |  |  |  |  |  |  |  |  |  |  |  | 1
TP9 | +VccMAX3185 | TestPoint:TestPoint_Loop_D2.54mm_Drill1.5mm_Beaded | ~ | HAND |  | NA |  |  |  |  |  |  |  |  |  |  |  |  |  |  | 1
TP10 | +VccMCP9600 | TestPoint:TestPoint_Loop_D2.54mm_Drill1.5mm_Beaded | ~ | HAND |  | NA |  |  |  |  |  |  |  |  |  |  |  |  |  |  | 1
TP20 | +24V | TestPoint:TestPoint_Loop_D2.54mm_Drill1.5mm_Beaded | ~ | HAND |  | NA |  |  |  |  |  |  |  |  |  |  |  |  |  |  | 1
TPSwitched_Fan_Power1 | Switched_Fan_Power | TestPoint:TestPoint_Loop_D2.54mm_Drill1.5mm_Beaded | ~ | HAND |  | NA |  |  |  |  |  |  |  |  |  |  |  |  |  |  | 1
TP_CIPO1 | CIPO | TestPoint:TestPoint_Loop_D2.54mm_Drill1.5mm_Beaded | ~ | HAND |  | 0 |  |  |  |  |  |  |  |  |  |  |  |  |  |  | 1
TP_COPI1 | COPI | TestPoint:TestPoint_Loop_D2.54mm_Drill1.5mm_Beaded | ~ | HAND |  | 0 |  |  |  |  |  |  |  |  |  |  |  |  |  |  | 1
TP_SCL1 | SCL | TestPoint:TestPoint_Loop_D2.54mm_Drill1.5mm_Beaded | ~ | HAND |  | NA |  |  |  |  |  |  |  |  |  |  |  |  |  |  | 1
TP_SCL2 | SCL1 | TestPoint:TestPoint_Loop_D2.54mm_Drill1.5mm_Beaded | ~ | HAND |  | NA |  |  |  |  |  |  |  |  |  |  |  |  |  |  | 1
TP_SDA1 | SDA | TestPoint:TestPoint_Loop_D2.54mm_Drill1.5mm_Beaded | ~ | HAND |  | NA |  |  |  |  |  |  |  |  |  |  |  |  |  |  | 1
TP_SDA2 | SDA1 | TestPoint:TestPoint_Loop_D2.54mm_Drill1.5mm_Beaded | ~ | HAND |  | NA |  |  |  |  |  |  |  |  |  |  |  |  |  |  | 1
TP_SD_DET1 | TP_SD_DET | TestPoint:TestPoint_Loop_D2.54mm_Drill1.5mm_Beaded | ~ | HAND |  | NA |  |  |  |  |  |  |  |  |  |  |  |  |  |  | 1
TP_SPI_SCK1 | SPI_SCK | TestPoint:TestPoint_Loop_D2.54mm_Drill1.5mm_Beaded | ~ | HAND |  | NA |  |  |  |  |  |  |  |  |  |  |  |  |  |  | 1
TP_VIN1 | VIN1 | TestPoint:TestPoint_Loop_D2.54mm_Drill1.5mm_Beaded | ~ | HAND |  | NA |  |  |  |  |  |  |  |  |  |  |  |  |  |  | 1
JP9, JP10, JP15 | MAX31850K | PubInv_KiCad_PCB:Adafruit_MAX31850K_Module | https://www.adafruit.com/product/1727 | HAND |  | 14.95 |  |  | Thermocouple Amplifier with 1-Wire Breakout Board - MAX31850K |  | adafruit | 1727 |  |  |  |  | 1727 | Adafruit |  |  | 3
JP16-JP18 | MAX31855 | PubInv_KiCad_PCB:Adafruit_MAX31855_Module | https://www.adafruit.com/product/269 | HAND |  | 14.95 |  |  | Thermocouple Amplifier MAX31855 breakout board (MAX6675 upgrade) |  | adafruit | 269 |  |  |  |  | 269 | Adafruit |  |  | 3
JP19-JP21 | MCP9600 | PubInv_KiCad_PCB:Adafruit_MCP9600_Module | https://www.adafruit.com/product/4101 | HAND |  | 15.95 |  |  | Adafruit MCP9600 I2C Thermocouple Amplifier - K, J, T, N, S, E, B and R Type T |  | adafruit | 4101 |  |  |  |  | 4101 | Adafruit |  |  | 3
MF3 | Stacking Headers Pins Kit | NA | https://www.amazon.com/Treedix-Stacking-Headers-Stackable-Compatible/dp/B08G4FGBPQ/ref=sr_1_6 | HAND |  | 4.5 |  |  | Stacking Headers Pins Kit Stackable Female Headers Compatible with Arduino Mega 2560(28pcs in Total) |  | Amazon | https://www.amazon.com/Treedix-Stacking-Headers-Stackable-Compatible/dp/B08G4FGBPQ/ref=sr_1_6 |  |  |  | YES | PCB_BKT_OEDCS_01 | TreeDix |  |  | 1
C1-C15, C20, C21, C23 | 39pF | Capacitor_SMD:C_0603_1608Metric_Pad1.08x0.95mm_HandSolder | https://datasheet.lcsc.com/lcsc/1811082118_YAGEO-CC0603JRNPO9BN390_C107049.pdf | SMT |  | 0 |  |  | 50V 39pF NP0 Â±5% 0603 Multilayer Ceramic Ca |  | JLCPCB | C107049 |  |  |  | NO | CC0603JRNPO9BN390 | YAGEO |  |  | 18
C16-C19, C24 | 1uF | Capacitor_SMD:C_0603_1608Metric_Pad1.08x0.95mm_HandSolder | CC0603JRX7R9BB104.pdf | SMT |  | 0 |  |  | 50V 1uF Â±5% 0603 Multilayer Ceramic Ca |  | JLCPCB | C91183 |  |  |  | NO | CC0603JRX7R9BB104 | YAGEO |  |  | 5
C22 | 10nF | Capacitor_SMD:C_0603_1608Metric_Pad1.08x0.95mm_HandSolder | ~ | SMT |  | 0.01 |  |  | 50V 10nF NP0 Â±5% 0603 Multilayer Ceramic Capacitors MLCC - SMD/SMT ROHS |  | JLCPCB | C389113 |  |  |  |  | CC0603JRNPO9BN103 | YAGEO |  |  | 1
D1, D2 | 5.1V | Diode_SMD:D_MiniMELF | https://assets.nexperia.com/documents/data-sheet/BZV55_SER.pdf BZV55B3V3 | SMT |  | 0.04 |  |  | Â±5% Single 1W 5.1V MELF Zener Diodes ROHS |  | JLCPCB | C841097 |  |  |  |  | DL4733A | LGE |  |  | 2
D3 | 1N5819WS | Diode_SMD:D_SOD-323 | https://datasheet.lcsc.com/lcsc/2204281430_Guangdong-Hottech-1N5819WS_C191023.pdf | SMT |  | 0.01 |  |  | 40V 600mV@1A 1A SOD-323 Schottky Barrier Diodes (SBD) ROHS |  | JLCPCB | C191023 |  |  |  |  | 1N5819WS | Guangdong Hottech |  |  | 1
D4 | RED 0603 | LED_SMD:LED_0603_1608Metric_Pad1.05x0.95mm_HandSolder | ~ | SMT | Optoelectronics | 0.01 | http://optoelectronics.liteon.com/upload/download/DS22-2000-109/LTST-C171KRKT.pdf | /product-detail/en/lite-on-inc/LTST-C171KRKT/160-1427-1-ND/386800 | LED RED CLEAR SMD | 160-1427-1-ND | JLCPCB | C2286 |  |  | LED Indication - Discrete |  | LTST-C171KRKT | Lite-On Inc. |  | Active | 1
J1 | DB9_Female_MountingHoles | Connector_Dsub:DSUB-9_Female_Horizontal_P2.77x2.84mm_EdgePinOffset4.94mm_Housed_MountingHolesOffset7.48mm | C141882_D-DMR009PF-D002.pdf | HAND |  | 0.27 |  |  | 9P Female D-Sub Shrouded 2 3A -50â„ƒ~+105â„ƒ Plugin D-Sub/DVI/HDMI Connectors ROHS |  | JLCPCB | C141882 |  |  |  |  | D-DMR009PF-D002 | Ckmtw(Shenzhen Cankemeng) |  |  | 1
J2-J6 | Conn_01x08 | Connector_PinSocket_2.54mm:PinSocket_1x08_P2.54mm_Vertical | https://jlcpcb.com/partdetail/Hctl-PZ254_1_08_Z_85/C2894931 | HAND |  | 0.08 |  |  | 3A Straight Square Pins 2.5mm 8P 6mm -40â„ƒ~+105â„ƒ 3mm 2.54mm Plugin Black 1x8P Plugin,P=2.54mm Pin Headers ROHS |  | JLCPCB | C2894931 |  |  |  |  | PZ254-1-08-Z-8.5 | HCTL |  |  | 5
J7, J9, J14, J26, J29 | Conn_01x10 | Connector_PinSocket_2.54mm:PinSocket_1x10_P2.54mm_Vertical | https://jlcpcb.com/partdetail/Hctl-PZ254_1_10_Z_85/C2894933 | HAND |  | 0.09 |  |  | 3A Straight Square Pins 2.5mm 10P 6mm -40â„ƒ~+105â„ƒ 3mm 2.54mm Plugin Black 1x10P Plugin,P=2.54mm Pin Headers ROHS |  | JLCPCB | C2894933 |  |  |  |  | PZ254-1-10-Z-8.5 | HCTL |  |  | 5
J8 | Conn_02x18_Odd_Even | Connector_PinSocket_2.54mm:PinSocket_2x18_P2.54mm_Vertical | C132131_DS1023-2_18SF11.pdf | HAND |  | 0.34 |  |  | 2.54mm 2.54mm åŒæŽ’ 36P Straight 2x18P Plugin,P=2.54mm Female Headers ROHS |  | JLCPCB | C132131 |  |  |  |  |  |  |  |  | 1
J10, J27 | Conn_02x12_Odd_Even | PubInv_KiCad_PCB.pretty:PinHeader_2x12_P2.00mm_Vertical_JST | https://www.jst-mfg.com/product/pdf/eng/ePHD.pdf | HAND |  | 1000000 |  |  | Conn_02x12_Odd_Even |  | JLCPCB | C160327 | JLCPCB | ?https://jlcpcb.com/partdetail/Jst_SalesAmerica-B24B_PHDSS_B_LF_SN/C160327? |  |  | B24B-PHDSS |  | B24B-PHDSS |  | 2
J11-J13, J25, J28, J30-J34 | Screw_Terminal_01x02 | TerminalBlock_TE-Connectivity:TerminalBlock_TE_282834-2_1x02_P2.54mm_Horizontal | DB128V-5.08-2P-GN-S.pdf | HAND |  | 0.15 |  |  | 1x2P 20A -40â„ƒ~+105â„ƒ 300V Green 12~30 Straight pin 5.08mm 2.5 1 2 Plugin,P=5.08mm Screw terminal ROHS |  | JLCPCB | C265283 |  |  |  |  | DB125-2.54-2P-GN-S | DIBO |  |  | 10
J15 | DB25_Female_MountingHoles | Connector_Dsub:DSUB-25_Female_Horizontal_P2.77x2.84mm_EdgePinOffset4.94mm_Housed_MountingHolesOffset7.48mm | C190083_D-DMR025PF-D002.pdf | HAND |  | 0.72 |  |  | 25P Female D-Sub Shrouded 2 3A -50â„ƒ~+105â„ƒ Plugin D-Sub/DVI/HDMI Connectors ROHS |  | JLCPCB | C190083 |  |  |  |  | D-DMR025PF-D002 | Ckmtw(Shenzhen Cankemeng) |  |  | 1
J16, J18, J20, J24, J37 | Conn_01x04 | Connector_PinHeader_2.54mm:PinHeader_1x04_P2.54mm_Vertical | HB-PH3-25414PB2GOP.pdf | HAND |  | 0.03 |  |  | 2.54mm Plugin 3A 4P -40â„ƒ~+105â„ƒ Straight 1x4P 8.5mm Top Square Holes Plugin,P=2.54mm Female Headers ROHS |  | JLCPCB | C6332197 |  |  |  |  | HB-PH3-25414PB2GOP | Hanbo Electronic |  |  | 5
J17 | Conn_01x05 | Connector_PinHeader_2.54mm:PinHeader_1x05_P2.54mm_Vertical | C2897368_PM254-1-05-Z-8.5.pdf | HAND |  | 0.08 |  |  | 2.54mm Plugin 3A 5P -40â„ƒ~+105â„ƒ Straight 1x5P 8.5mm Top Square Holes Plugin,P=2.54mm Female Headers ROHS |  | JLCPCB | C2897368 |  |  |  |  | PM254-1-05-Z-8.5 | HCTL |  |  | 1
J19 | Conn_01x07 | Connector_PinHeader_2.54mm:PinHeader_1x07_P2.54mm_Vertical | C2932672_KH-2.54FH-1X7P-H8.5.pdf | HAND |  | 0.05 |  |  | 2.54mm Plugin 3A 7P -40â„ƒ~+105â„ƒ Straight 1x7P 8.5mm Top Square Holes Plugin,P=2.54mm Female Headers ROHS |  | JLCPCB | C2932672 |  |  |  |  |  |  |  |  | 1
J21 | RJ12_6P6C_HORZ | PubInv_KiCad_PCB:RJ12_Amphenol_54601 | https://datasheet.lcsc.com/lcsc/1811141146_TE-Connectivity-5555165-1_C305981.pdf | HAND |  | 0.89 |  |  | Jack Modular Connector 6p6c (RJ11, RJ12, RJ14, RJ25) 90Â° Angle (Right) Unshielded Cat3 |  | JLCPCB | C305981 | Digikey | A31422-ND |  | YES | 5555165-1 | TE Connectivity |  |  | 1
J22, J23 | 0.100_2Pin | Connector_PinHeader_2.54mm:PinHeader_1x02_P2.54mm_Vertical | https://datasheet.lcsc.com/lcsc/1811011511_Amphenol-ICC-68000-102HLF_C168673.pdf | HAND | Connectors, Interconnects | 0.15 |  |  | HEADER VERT 2POS 2.54MM |  | JLCPCB | C168673 |  |  | Rectangular Connectors - Headers, Male Pins | YES | 68000-102HLF | Amphenol ICC |  | Active | 2
J35, J36 | Conn_02x05_Odd_Even | Connector_IDC:IDC-Header_2x05_P2.54mm_Vertical | https://www.we-online.com/catalog/datasheet/61201021621.pdf | HAND |  | 0.48 |  |  | 2.54mm Box 10Pin Male Straight |  | JLCPCB | C5665 | Mouser | 710-61201021621 |  |  | 61201021621 | Wurth |  |  | 2
Q1, Q3-Q14 | BSS138 | Package_TO_SOT_SMD:SOT-23 | https://www.onsemi.com/pub/Collateral/BSS138-D.PDF | SMT |  | 0.02 |  |  | 50V 220mA 3.5Î©@10V,220mA 360mW 1.5V@1mA N Channel SOT-23 MOSFETs ROHS |  | JLCPCB | C400505 |  |  |  | -- mixed values -- | BSS138 | -- mixed values -- |  |  | 13
Q2 | NCE01P30K | Package_TO_SOT_SMD:TO-252-2 | https://jlcpcb.com/partdetail/117243-NCE01P30K/C115991 | SMT |  | $0.51 |  |  | P Channel -100V 30A(Tc) 2.5V @ 250uA 58mÎ© @ 15A,10V 120W(Tc) TO-252-2L MOSFET RoHS |  | JLCPCB | C115991 |  |  |  |  | NCE01P30K | Wuxi NCE Power Semiconductor |  |  | 1
R1-R16, R31, R33, R48-R50, R59, R66, R73, R76, R79, R80, R82, R84, R88, R91-R100, R109-R112, R117, R119, R121, R122, R140, R141, R144-R166, R169 | 1R0 | Resistor_SMD:R_0603_1608Metric_Pad0.98x0.95mm_HandSolder | ~ | SMT |  | 0 |  |  | 0.1W Â±5% 1Î© 0603 Chip Resistor - Surface Mount ROHS |  | JLCPCB | C269434 |  |  |  | NO | RMC060315%N | TyoHM |  |  | 74
R18-R29, R36-R38, R42, R45, R47, R54, R57, R58, R62, R115, R116, R130, R172, R173 | 1K | Resistor_SMD:R_0603_1608Metric_Pad0.98x0.95mm_HandSolder | https://datasheet.lcsc.com/lcsc/1811101310_TyoHM-RMC06031K1-N_C269704.pdf | SMT |  | 0 |  |  | 0.1W Â±1% 1kÎ© 0603 Chip Resistor - Surface Mount ROHS |  | JLCPCB | C269704 |  |  |  | NO | RMC06031K1%N | TyoHM |  |  | 27
R32 | 4M7 | Resistor_SMD:R_0603_1608Metric_Pad0.98x0.95mm_HandSolder | C23163_0603WAF4704T5E.pdf | SMT |  | 0 |  |  | 100mW Thick Film Resistors Â±100ppm/â„ƒ Â±1% 4.7MÎ© 0603 Chip Resistor - Surface Mount ROHS |  | JLCPCB | C23163 |  |  |  |  | 0603WAF4704T5E | TyoHM |  |  | 1
R39-R41, R44, R46, R56, R61, R64, R65, R67-R70, R81, R101, R103-R108, R113, R114, R123, R124, R126, R127, R142, R143 | 10K | Resistor_SMD:R_0603_1608Metric_Pad0.98x0.95mm_HandSolder | https://datasheet.lcsc.com/lcsc/1811101310_TyoHM-RMC06031K1-N_C269704.pdf | SMT |  | 0 |  |  | 100mW Â±1% 10kÎ© 0603 Chip Resistor - Surface Mount ROHS |  | JLCPCB | C269701 |  |  |  | NO | RMC060310KFN | TyoHM |  |  | 29
R71, R72, R129, R131-R139, R170, R171, R174-R179 | 39R | Resistor_SMD:R_0603_1608Metric_Pad0.98x0.95mm_HandSolder | ~ | SMT |  | 0 |  |  | 0.1W Â±1% 39Î© 0603 Chip Resistor - Surface Mount ROHS |  | JLCPCB | C325713 |  |  |  | NO | RMC0603391%N | TyoHM |  |  | 20
R77, R78, R83, R102, R125, R128, R167, R168 | 4K7 | Resistor_SMD:R_0603_1608Metric_Pad0.98x0.95mm_HandSolder | ~ | SMT |  | 0 |  |  | 1W Â±1% 4.7kÎ© 0603 Chip Resistor - Surface Mount ROHS |  | JLCPCB | C269713 |  |  |  |  | RMC 0603 4K7 F N | TyoHM |  |  | 8
S1, S2 | SWITCH_TACTILE_SPST-NO_0.05A_24V | PubInv_KiCad_PCB:Switch_Tactile_THT_6x6mm | https://www.te.com/commerce/DocumentDelivery/DDEController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 | HAND | Switches | 0.03 | https://www.te.com/commerce/DocumentDelivery/DDEController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 | /product-detail/en/te-connectivity-alcoswitch-switches/1825910-7/450-1804-ND/1731414 | Â±10% Â±100ppm/â„ƒ 10kÎ© Plugin Variable Resistors/Potentiometers ROHS |  | JLCPCB | C13828 | Digikey | 450-1804-ND | Tactile Switches |  | TE Connectivity 1825910-7, Dongguan Guangzhu Industrial C13828 | TE Connectivity ALCOSWITCH Switches |  | Active | 2
H1-H5 | MountingHole_Pad_3.5mm | PubInv_KiCad_PCB:MountingHole_3.5mm_Pad_Via | ~ | NA |  | 0 |  |  | MountingHole_Pad_3.5mm |  | NA | NA |  |  |  |  |  |  |  |  | 5
ISO1-ISO5 | MountingHole_Pad_3.5mm | PubInv_KiCad_PCB:MountingHole_3.5mm_Pad_Via | ~ | NA |  | 0 |  |  | MountingHole_Pad_3.5mm |  | NA | NA |  |  |  |  |  |  |  |  | 5
TP12 | ControllerVCC | TestPoint:TestPoint_Loop_D2.54mm_Drill1.5mm_Beaded | ~ | DNI |  | NA |  |  |  |  | NA | NA |  |  |  | NO |  |  |  |  | 1
TP13 | CPIO | TestPoint:TestPoint_Loop_D2.54mm_Drill1.5mm_Beaded | ~ | DNI |  | NA |  |  |  |  | NA | NA |  |  |  | NO |  |  |  |  | 1
TP14 | SCK | TestPoint:TestPoint_Loop_D2.54mm_Drill1.5mm_Beaded | ~ | DNI |  | NA |  |  |  |  | NA | NA |  |  |  | NO |  |  |  |  | 1
TP15 | COPI | TestPoint:TestPoint_Loop_D2.54mm_Drill1.5mm_Beaded | ~ | DNI |  | NA |  |  |  |  | NA | NA |  |  |  | NO |  |  |  |  | 1
TP16 | nCS | TestPoint:TestPoint_Loop_D2.54mm_Drill1.5mm_Beaded | ~ | DNI |  | NA |  |  |  |  | NA | NA |  |  |  | NO |  |  |  |  | 1
TP17 | I2C_VCC | TestPoint:TestPoint_Loop_D2.54mm_Drill1.5mm_Beaded | ~ | DNI |  | NA |  |  |  |  | NA | NA |  |  |  | NO |  |  |  |  | 1
TP18 | SCL_5V | TestPoint:TestPoint_Loop_D2.54mm_Drill1.5mm_Beaded | ~ | DNI |  | NA |  |  |  |  | NA | NA |  |  |  | NO |  |  |  |  | 1
TP19 | SDA_5V | TestPoint:TestPoint_Loop_D2.54mm_Drill1.5mm_Beaded | ~ | DNI |  | NA |  |  |  |  | NA | NA |  |  |  | NO |  |  |  |  | 1
JP1-JP8, JP11-JP14 | SolderJumper_3_Bridged12 | Jumper:SolderJumper-3_P1.3mm_Bridged12_RoundedPad1.0x1.5mm | NA | DNI |  | 0 |  |  | SolderJumper_3_Bridged12 |  | PublicInvention | NA |  |  |  |  | NA | NA |  |  | 12
MF1, MF2 | PCB_BKT_OEDCS_01 | NA | PCB_BKT_OEDCS_01 | HAND |  | 1000000 |  |  | PCB_BKT_OEDCS_01 |  | PublicInvention | PCB_BKT_OEDCS_01 |  |  |  | YES | PCB_BKT_OEDCS_01 | PublicInvention |  |  | 2
MF4 | PCB_OEDCS_Control_Ver_0.1 | NA | https://github.com/PubInv/NASA-COG/tree/develop/elec/Control%20Board/Control%20v1 | HAND |  | 1000000 |  |  | PCB for OEDCS_Controller Version 0.1 |  | PublicInvention | PCB_PolyVent_SPI_Controller_VER1 |  |  |  | YES | PCB_OEDCS_Control_Ver_0.1 | PublicInvention |  |  | 1

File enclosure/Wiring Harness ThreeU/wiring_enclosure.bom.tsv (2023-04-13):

Id | Description | Qty | Unit | Designators
1 | Connector, Anderson Power SB50 SB, Dual, 4 pins | 4 |  | X3, X4, X5, X6
2 | Connector, Crimp ferrule, spade | 46
3 | Connector, D-Sub, male, 25 pins | 1 |  | X2
4 | Connector, D-Sub, male, 9 pins | 1 |  | X1
5 | Connector, JST PHDR-24VS, female, 24 pins | 1 |  | CN2
6 | Connector, jumpers, 42 pins | 1 |  | Arduino_Due
7 | Wire, 0.25 mm², BK | 1.0 | m | W2
8 | Wire, 0.25 mm², BN | 1.5 | m | W2
9 | Wire, 0.25 mm², BU | 1.0 | m | W2
10 | Wire, 0.25 mm², GN | 1.0 | m | W2
11 | Wire, 0.25 mm², GY | 1.0 | m | W2
12 | Wire, 0.25 mm², OG | 1.5 | m | W2
13 | Wire, 0.25 mm², RD | 1.5 | m | W2
14 | Wire, 0.25 mm², VT | 1.0 | m | W2
15 | Wire, 0.25 mm², WH | 1.0 | m | W2
16 | Wire, 0.25 mm², YE | 1.5 | m | W2
17 | Wire, 1 mm², BN | 0.5 | m | W0
18 | Wire, 1 mm², OG | 0.5 | m | W0
19 | Wire, 1 mm², RD | 0.5 | m | W0
20 | Wire, 12 AWG, BK | 0.6 | //15ft | W7, W8, W9
21 | Wire, 12 AWG, GN | 0.6 | //15ft | W7, W8, W9
22 | Wire, 12 AWG, WH | 0.6 | //15ft | W7, W8, W9
23 | Wire, 6.0 mm², BK | 0.5 | m | W1
24 | Wire, 6.0 mm², RD | 0.5 | m | W1
25 | Wire, 6.00 mm², BK | 1.6 | m | W3, W4, W5, W6
26 | Wire, 6.00 mm², RD | 1.6 | m | W3, W4, W5, W6
27 | Wire, BK | 5000.0 | //15ft | power_cord
28 | Wire, GN | 5000.0 | //15ft | power_cord
29 | Wire, WH | 5000.0 | //15ft | power_cord

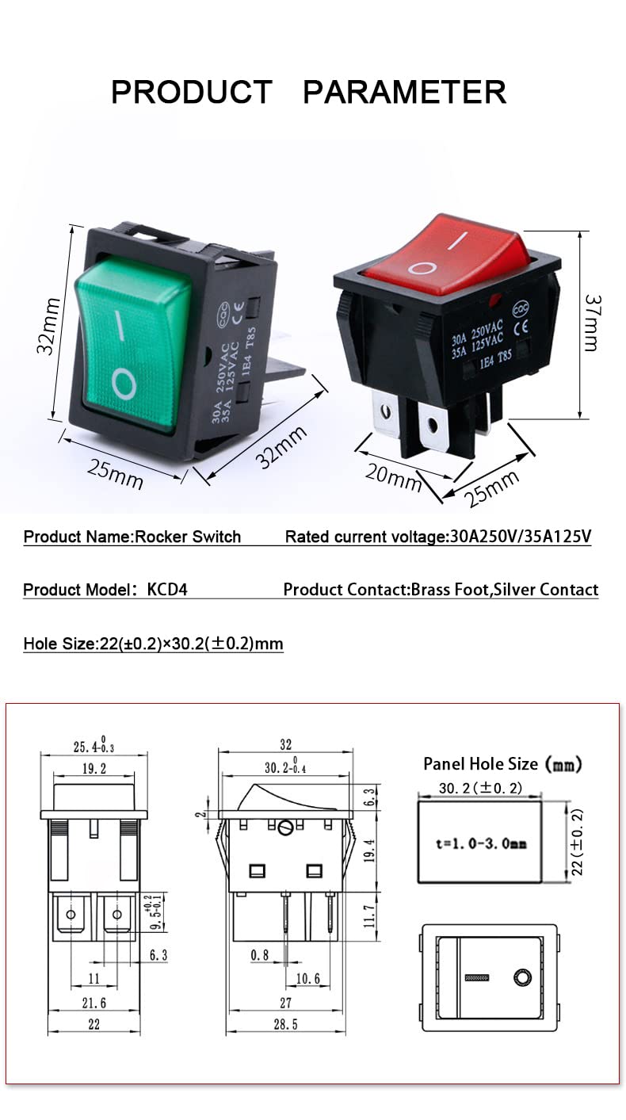
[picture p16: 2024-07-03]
frontpanel/Parts/RockerSwitch_61FPjCP-S0L._SL1413_.jpg

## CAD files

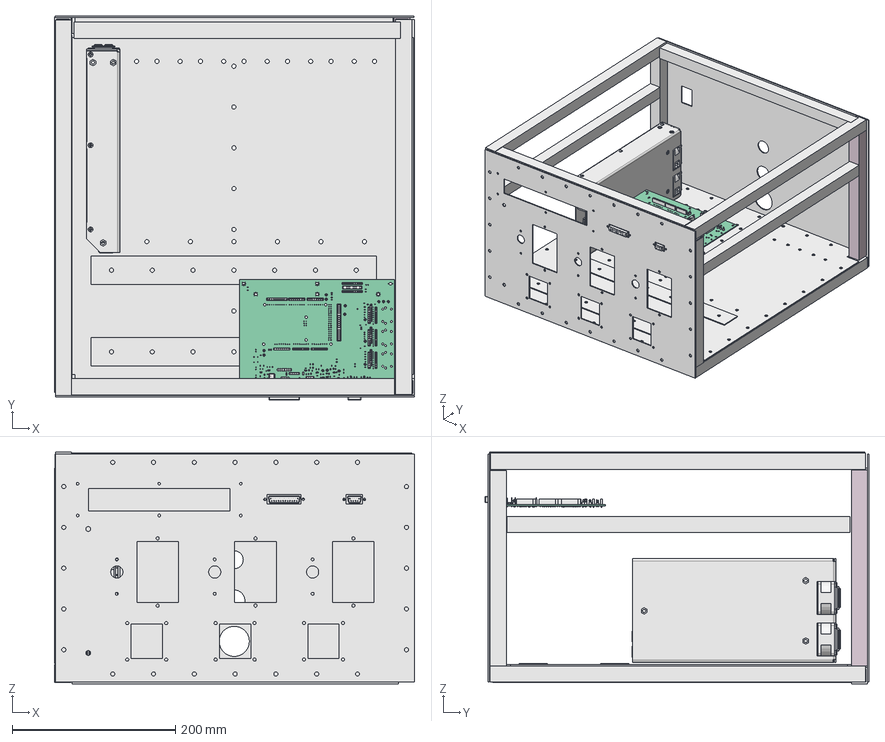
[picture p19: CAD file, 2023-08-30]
enclosure/FreeCADAssy/ASSY_ODECOS_V2.FCStd
441.5 x 470.6 x 283.8 mm
frontpanel_BodyBottomPlateV2_001
frontpanel_BodyCloneDIN_001
frontpanel_BodyDIN_Rail_001
frontpanel_frontpanel2_001
BodyEndPanelMounting_001
BodyVertRightSideFront20x20x240Tube
BodyFrontBottom20x20x400Tube
BodyLeftSideFront20x20x240
BodyWidthFrontBottom20x20x400
BodyRightBottom20x20x460
BodyLeftSideBottom20x20x460
BodyVertRightSideRear20x20x240
BodyVertLeftSideRear20x20x240
BodyDeptRightTop20x20x460
BodyDeptLeftTopper20x20x460
BodyWidthTopFront20x20x400
BodyWidthTopRear20x20x400
BodyRightMidBrace20x20x420
BodyLeftMidBrace20x20x420
6½Ȃބ¸M3_킔O
6½Ȃބ¸M3_킔O001
76-0000-0828_킔O
TO247_transistor_킔O
TO220_crystal Fe_킔O
TO247_transistor_킔O001
ȾW_킔O
ȾW_킔O001
ȾW_킔O002
ȾW_킔O003
ǟ킔O
ǟ킔O001
ǟ킔O002
ǟ킔O003
ǟ킔O004
ǟ킔O005
58-5501-0021_AK650_킔O
¶̗ҟ3P
¶̗ҟ3P001
¶̗ҟ3P002
ȾW_킔O005
ȾW_킔O006
ȾW_킔O007
ȾW_킔O008
TO220_crystal Fe_킔O001
TO220_crystal Fe_킔O002
58-2500-0062_AK Clip(30L)_킔O
58-2500-0063_AK Clip(45L no nut)_킔O
BOTTOM_킔O
6½Ȃބ¸ M4(T2.0)_킔O
6½Ȃބ¸ M4(T2.0)_킔O001
6½Ȃބ¸ M4(T2.0)_킔O002
6½Ȃބ¸ M4(T2.0)_킔O003
6½Ȃބ¸ M4(T2.0)_킔O004
6½Ȃބ¸ M4(T2.0)_킔O005
6½Ȃބ¸ M4(T2.0)_킔O006
6½Ȃބ¸ M4(T2.0)_킔O007
6½Ȃބ¸ M4(T2.0)_킔O008
AE800_PCB
TO247_transistor_킔O002
bridge_킔O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

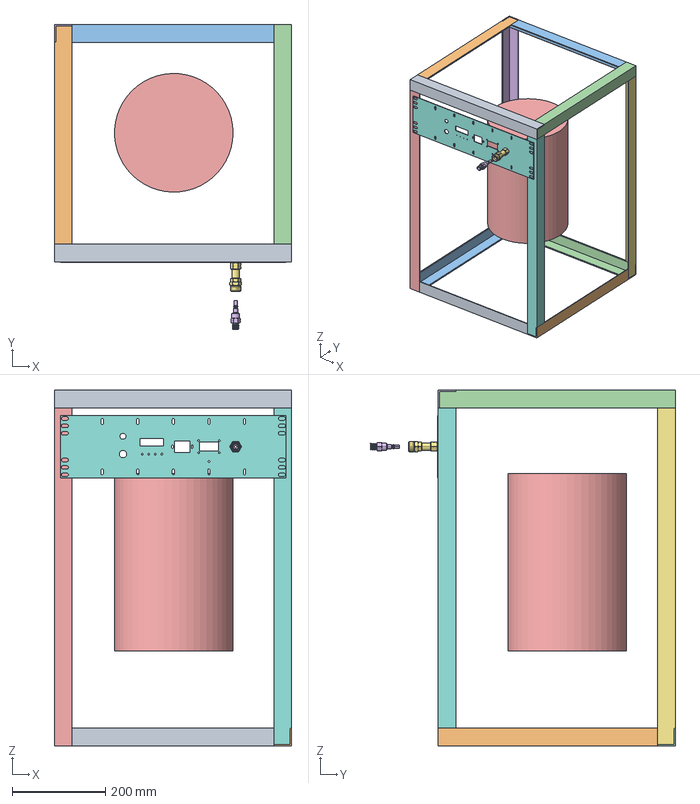
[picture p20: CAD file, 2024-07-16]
Plant20x30inch/AssyPlantCage.FCStd
508.1 x 653.6 x 762.5 mm
AngleIron20inch_FrontBottom
AngleIron20inch_RightBottom
AngleIron20inch_LeftBottom
AngleIron20inch_RearBottom
AngleIron30inch_LeftFront
AngleIron30inch_LeftRear
AngleIron30inch_RightRear
AngleIron30inch_RightFront
AngleIron20inch_FrontTop
AngleIron20inch_LeftTop
AngleIron20inch_RearTop
AngleIron20inch_RightTop
Entabulator10x15_001
7934A6_Quick-Disconnect Hose Coupling Set for Compre1_7934A6_Quick-Disconnect Hose Coupling Set for Compre001_001
7934A6_Quick-Disconnect Hose Coupling Set for Compre1_7934A6_Quick-Disconnect Hose Coupling Set for Compre003_001
ThreeU_Chassis_BodyPlantPanelWithHoles_001

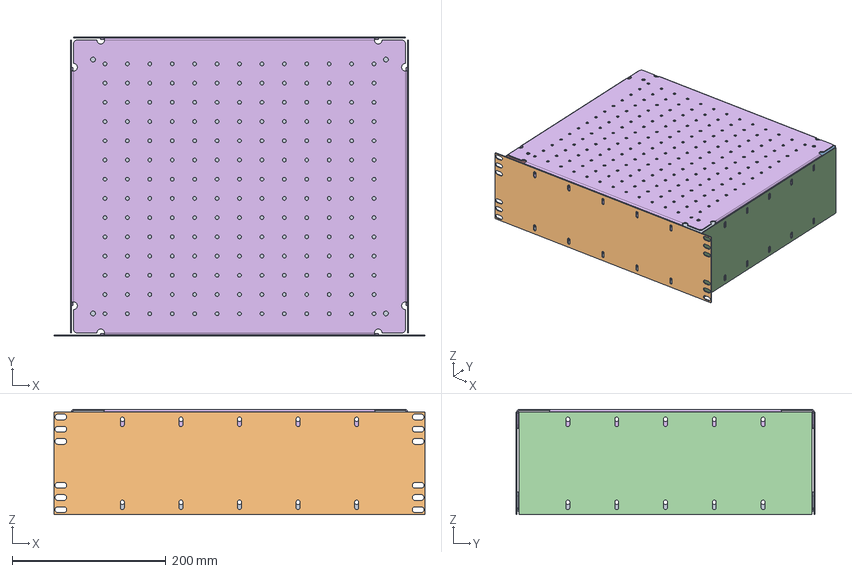
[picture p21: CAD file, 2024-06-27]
enclosure/ThreeU/ThreeU_Assembly_SinglePower.FCStd
482.6 x 389.4 x 136.9 mm
ThreeU_Chassis_BodyChassis_18x15_001
ThreeU_Chassis_BodyFrontPanelThreeU_001
ThreeU_Chassis_BodyRearPanel_001
ThreeU_Chassis_BodySidePanel_001
ThreeU_Chassis_BodySidePanel_002
ThreeU_Chassis_BodyChassis_18x15_002

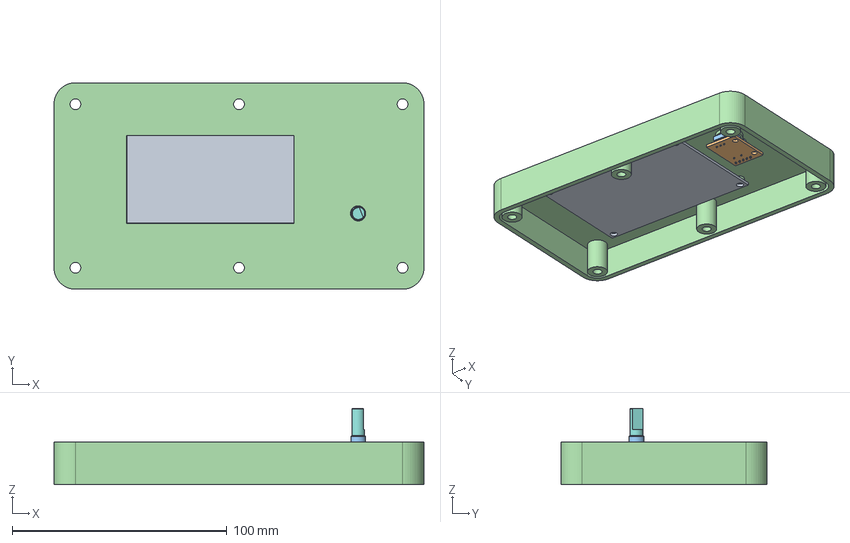
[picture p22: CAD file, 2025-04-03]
display/OLED_2.4inchHiLetGo.FCStd
172.4 x 96.2 x 35.6 mm
pcb
mtg flange
body_encoder
5 pin header
90d pin_header
90d pin_header001
90d pin_header002
90d pin_header003
90d pin_header004
decal_encoder
decal_encoder001
decal_encoder002
decal_encoder003
decal_encoder004
decal_encoder005
decal_encoder006
decal_encoder007
decal_encoder008
decal_encoder009
decal_encoder010
decal_encoder011
decal_encoder012
decal_encoder013
decal_encoder014
pins_encoder body_2
pins_encoder body_003
shaft_encoder
pins_encoder body_004
pins_encoder body_005
pins_encoder body_006
BodyDisplayMountBody

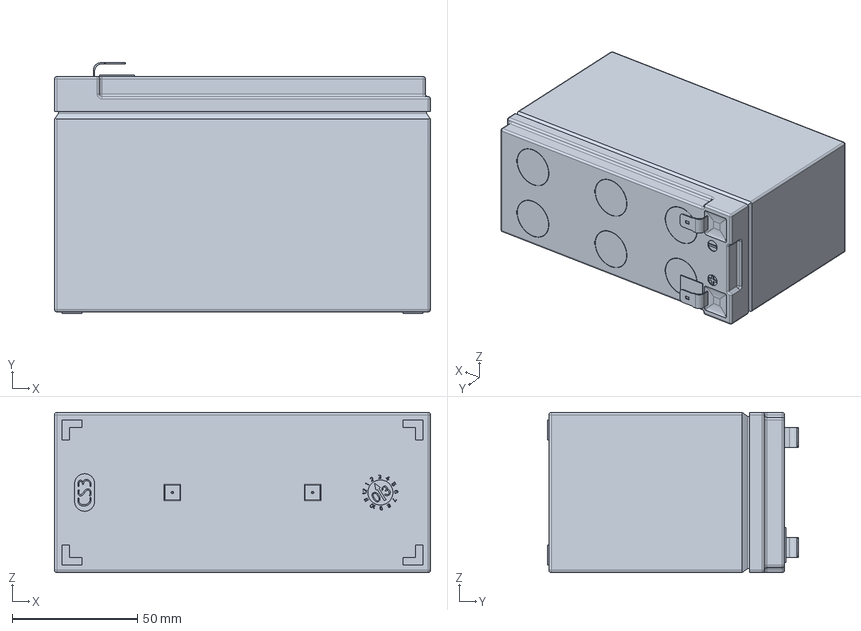
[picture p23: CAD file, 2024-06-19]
enclosure/3D models/12v_sla_battery.stp
150.0 x 100.0 x 64.0 mm

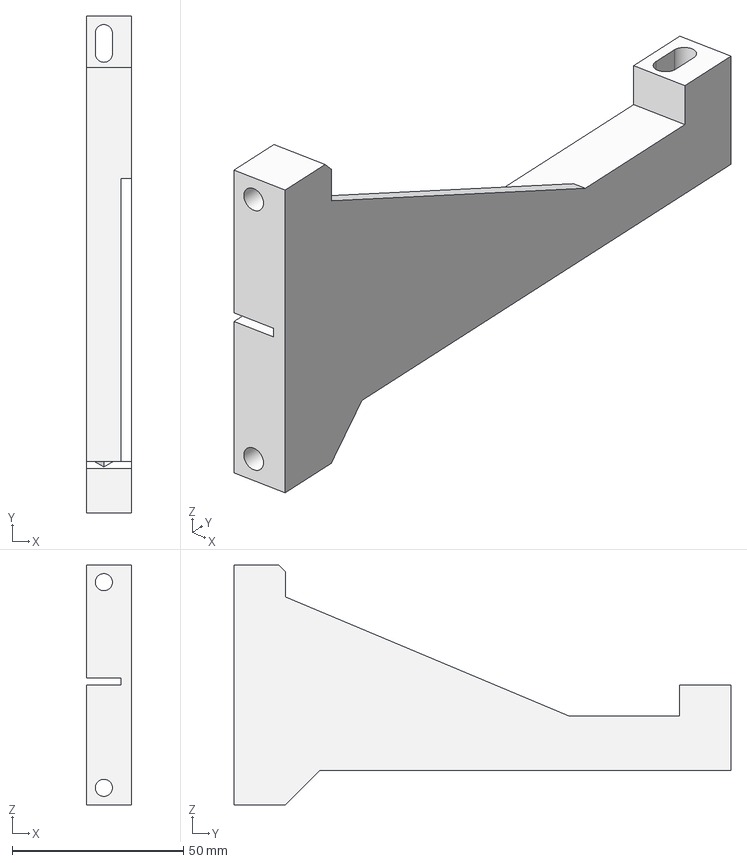
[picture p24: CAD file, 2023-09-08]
enclosure/FreeCADAssy/ControllerSupportRT/ControllerSupportRT-PartBodySupportRT.step
13.0 x 145.0 x 70.0 mm

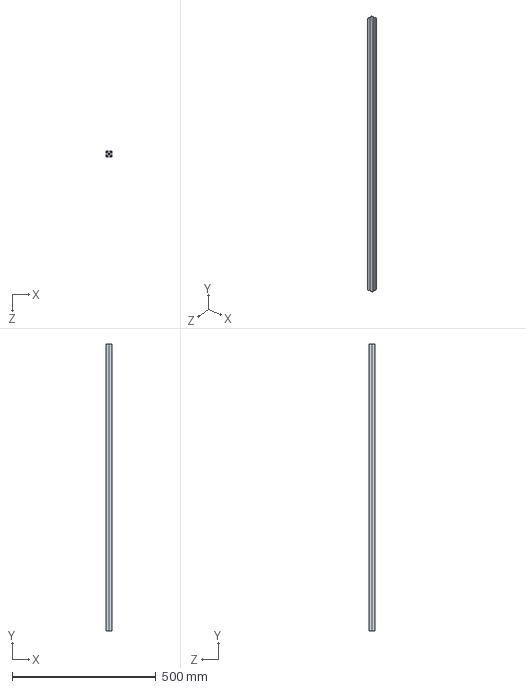
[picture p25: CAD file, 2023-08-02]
enclosure/FreeCADAssy/PartsEnclosure/Aluminium extrusion 20x20x1000.STEP
20.0 x 1000.0 x 20.0 mm

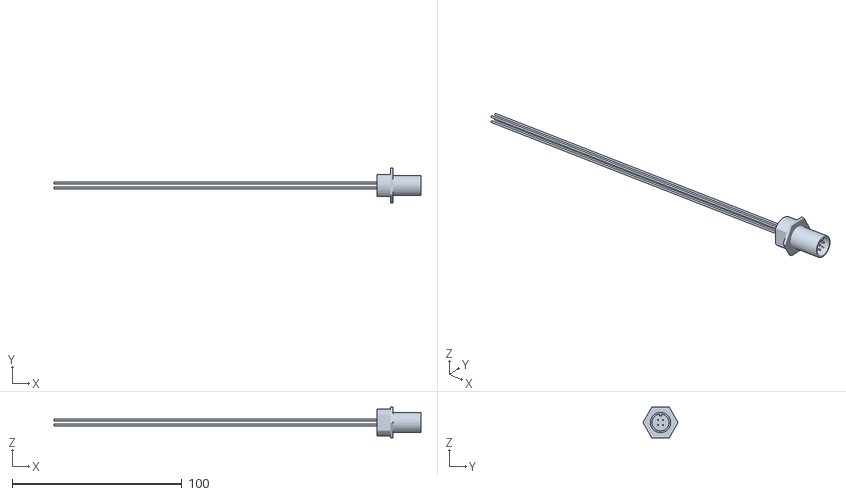
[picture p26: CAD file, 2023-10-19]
enclosure/M12BulkHead/M12BulkHeadToBlunt-PartPadWries.stl
216.5 x 20.8 x 18.0

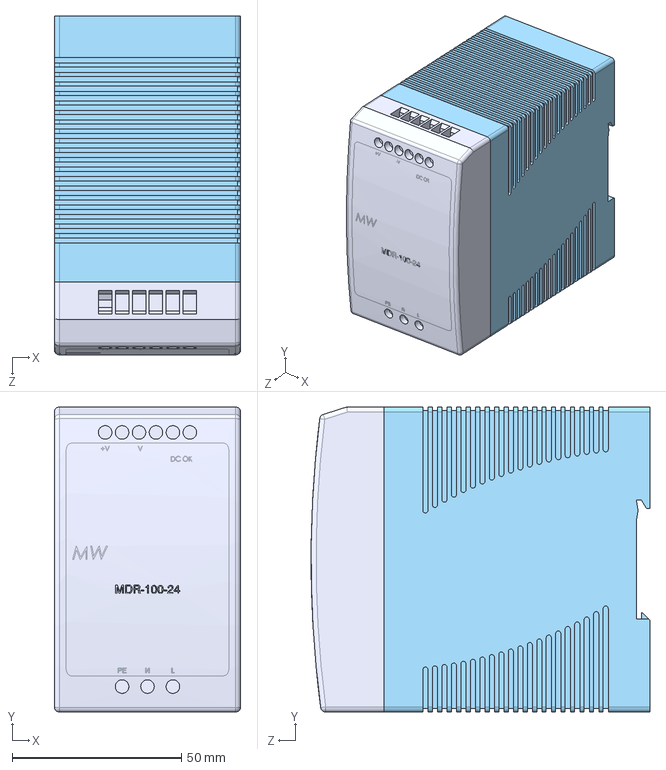
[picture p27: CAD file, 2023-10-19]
enclosure/MeanWell/ALIM MEAN WELL MDR-100-24.STEP
55.0 x 90.0 x 100.0 mm

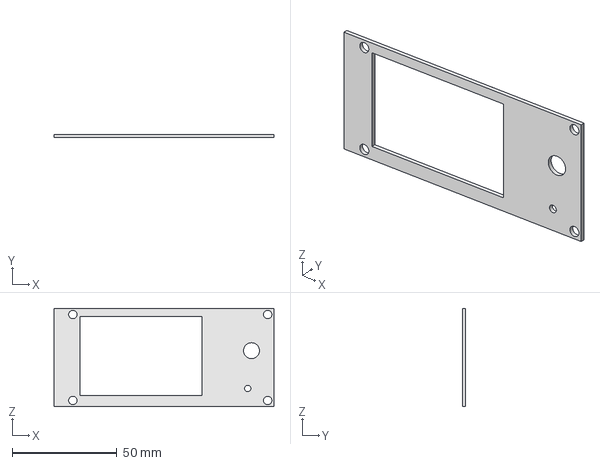
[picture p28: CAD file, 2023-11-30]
enclosure/RepRapDisplay/BigTreeTech/BigTreeTechHolesInPanel.FCStd
105.0 x 1.57 x 47.0 mm

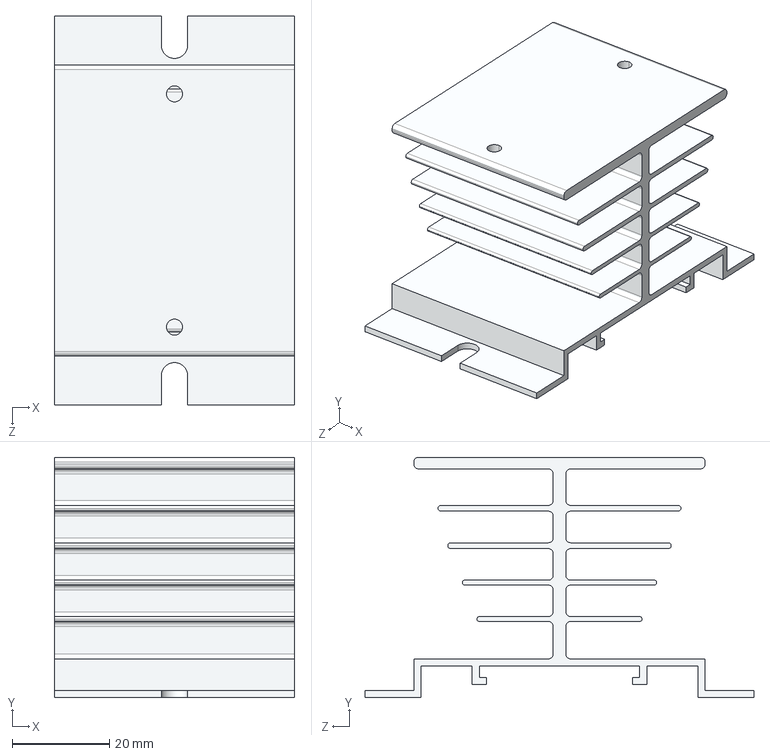
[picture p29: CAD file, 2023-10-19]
enclosure/SSR_2D3D_538 B/Solid State Relay Heat Sink, SSR-40DD.STEP
49.4 x 49.5 x 80.0 mm

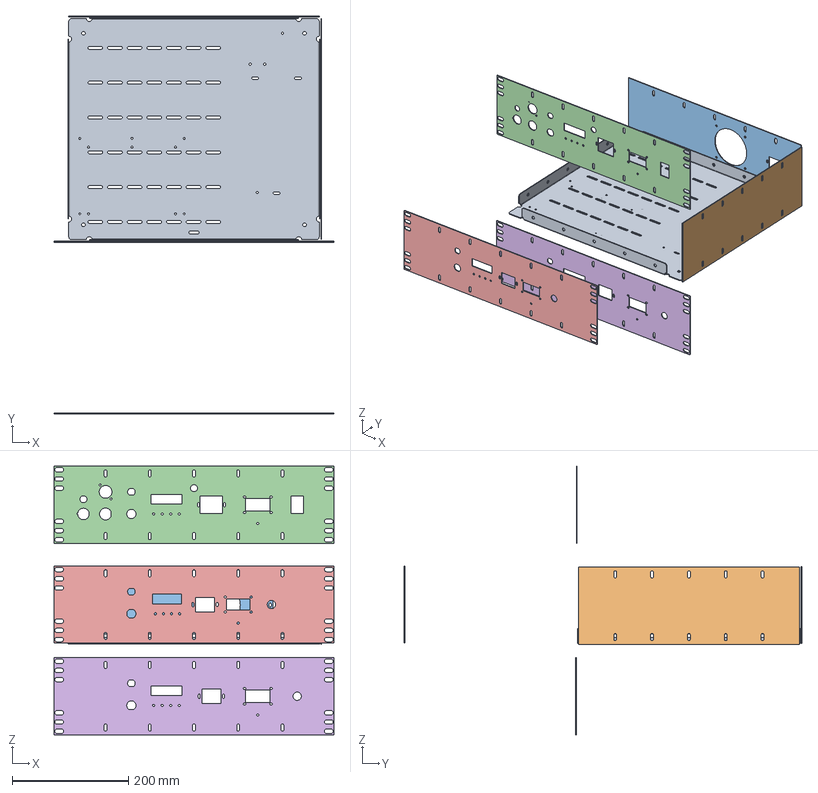
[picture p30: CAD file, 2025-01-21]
enclosure/ThreeU/ThreeU_Chassis.FCStd
482.6 x 686.0 x 463.3 mm
BodyChassis_18x15
BodySidePanel
BodyRearPanelWithHoles
BodyFrontPanelWithHoles
BodyPlantPanelWithHoles_Old
BodyPlantPanel

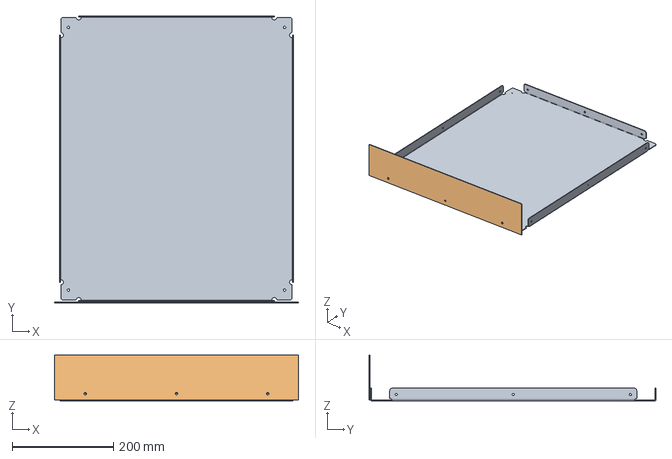
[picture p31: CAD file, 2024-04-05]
enclosure/TwoU/TwoU_Chassis.FCStd
482.6 x 567.0 x 90.5 mm
BodyChassis
BodyFrontPanelTwoU

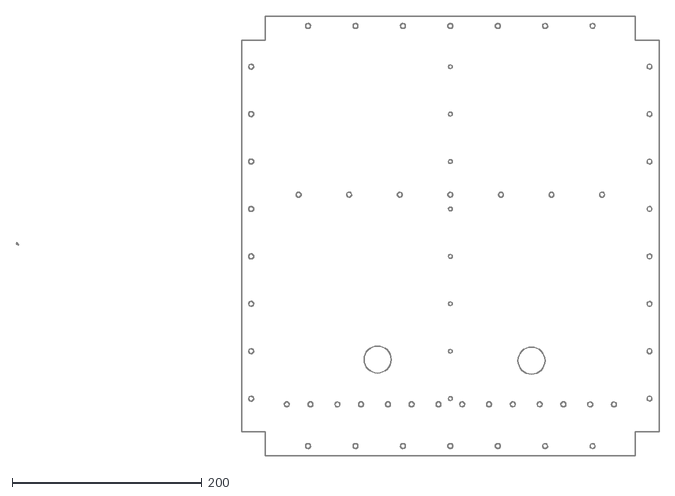
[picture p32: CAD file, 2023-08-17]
frontpanel/BottomPlateV1 edit.dxf
678.0 x 463.0

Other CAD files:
frontpanel/Parts/Mech/Banana Socket (Green).step
frontpanel/Parts/Mech/DB25_DB9/DB25_STEP/c-5747846-4-a-3d.stp
frontpanel/Parts/Mech/DB25_DB9/DB9_STEP/c-2311765-1-b-3d.stp
frontpanel/Parts/Mech/GX/gx-16-connector-4-pins-1.snapshot.3/GX-16 Connector 4 Pins.stp
enclosure/3D models/2020_profile.scad
enclosure/3D models/aluminium_extrusion_plate_brackets.scad
enclosure/3D models/customizable_aluminium_extrusion_plate_brackets.scad
enclosure/3D models/enclosure.scad
Plant20x30inch/AngleIron20inch.FCStd
Plant20x30inch/AngleIron30inch.FCStd
Plant20x30inch/Entabulator10x15.FCStd
Plant20x30inch/O2Quick.FCStd
Plant20x30inch/Part Models/5272K191_Yor-Lok Fitting for Copper Tubing.STEP
Plant20x30inch/Part Models/5305K401_Yor-Lok Fitting for Stainless Steel Tubing.STEP
Plant20x30inch/Part Models/7919A51_Hose Fitting for Compressed Gas.STEP
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

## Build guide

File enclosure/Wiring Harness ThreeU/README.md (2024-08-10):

## Overview

The `Wiring Harness` diagrams allows for constructing cable harnesses to interconnect various components.
The BOM for the 'Wiring Harness' consists of all components needed to construct a wiring harness.
This can be used to construct a new O:

##  BOM

### Sub-Assemblies
#### Front Panel Assembly
##### Order of Assembly:
* Press fit ON-OFF pump/standby switch
* Press fit ON-OFF Power rocker switch
* Install the four Thermocouple connectors
    * Cut TC hookup wire, Yellow + and Red -
        1. 6"
        2. 8" 
        3. 9.5"
        4. 11.5"
* Install connector labeled "Pressure"
* Install connector labeled "Fan"
    * 
* Install connector labeled "Stack"
* Install connector labeled "Heater"
* Install connector labeled "Fault" LED
* Install On/Flashing/Off LED
* Install connector labeled "LAN"
* Install connector labeled "USB"
* Install ground lugs

#### Rear Panel Assembly
##### Order of Assembly:
* Install C20 using two ''#6-32 x '¾ IN' flat philips screws.
* C20 should be in line with the PSU attached to the Base-Plate
* Add WH1 to panel mounted C20
* Install fan assembly the order is Fan shroud -> Rear Panel -> Fan
* Use plastic screws for the fan assmebly
* Fan pushes air into the case, the arrow goes towards the inside of the case
* Orient the fan such that the wire exits towards the Base-Plate
* Install Ground Lug, such that the ground lug is below C20

#### Base-Plate and Rails Assembly
##### Order of Assembly:
* Install PSU, using three screws
* Install brass lugsfor OEDCS control board
* Install DIN rail
* Install SSR and DIN mounted heatsink
* Install battery holder
* Install 12v and 24v PSU on DIN rail
* Prewire Din rail segments
* Install OEDCS control board
* Install DIN rail segments
* Install 12v SLA batttery
* Hook up wires
* Install side panels
* Install rack mount rail system

#### Top-Plate Assembly
##### Order of Assembly:
* On O2 handling systems, feed through 12v power cable 

#### Order of Assembly
* Base-Plate and Rails Assembly
* Rear Panel Assembly
* Front Panel Assembly
* Top-Plate Assembly

```mermaid
flowchart TD
    oedcs---|Heater|srva
    oedcs---|Fan|blower
    oedcs-.-|USB|usboedcs
    oedcs-.-|Ethernet|ethoedcs
    omega-.-|USBtoSerial|usbtoserial
    rack-.-|USB|usbdaq
    
    subgraph sbc[Single Board Computer]
    usbdaq[DATAQ PN]-.-pyscript["python script to log"]
    sbc[data logging-server]---backend["Backend data logger"]
    end
    
    subgraph omega[Omega Paramagnetic Analyzer]
    sbc[data log-server]---pyscript["python script to log"]
    end
    
    subgraph oedcs[OEDCS]
    [data logging-server]---backend["Backend data logger"]
    end
    
    subgraph rack[6U Rack]
    ggml[llama.cpp]---rpcb[RPC backend]
    end
    style hostn stroke:#66,stroke-width:2px,stroke-dasharray: 5 5
```

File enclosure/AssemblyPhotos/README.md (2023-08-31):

## File Descriptions / Quick View
This folder contains information related to the OEDCS **Serial_number1** build.

Memories of how this was assembled in March 2023

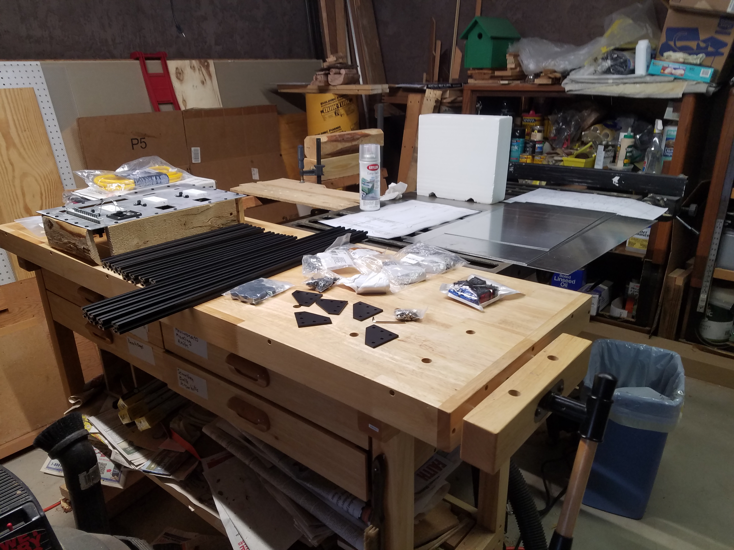
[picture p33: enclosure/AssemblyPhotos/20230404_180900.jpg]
   
Front panel was assembled with components first.  
Other parts staged for start of assembly.  

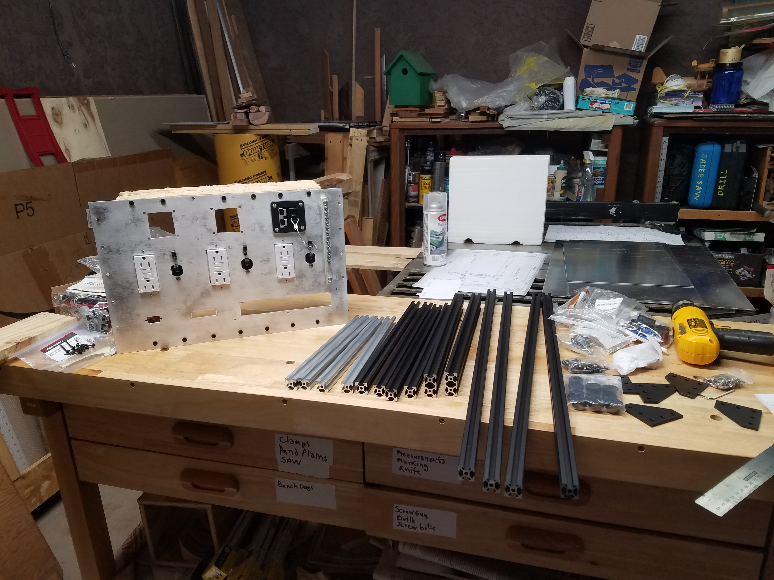
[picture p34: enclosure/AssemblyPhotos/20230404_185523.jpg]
 

Parts staged for start of assembly

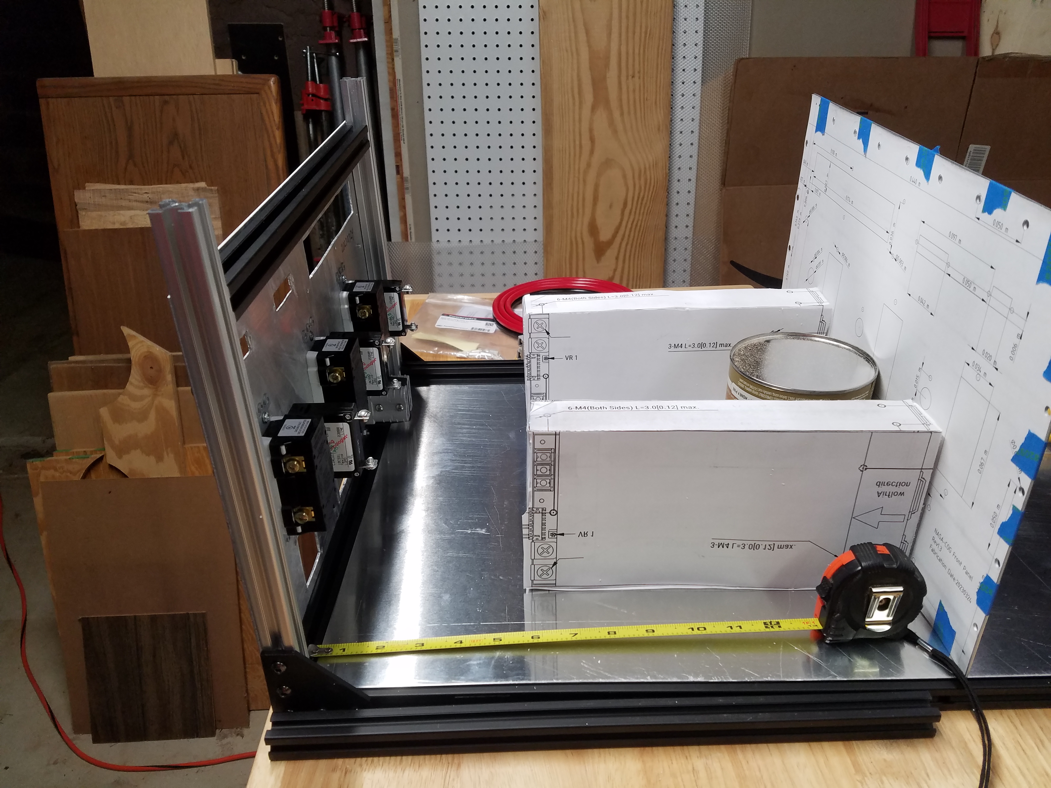
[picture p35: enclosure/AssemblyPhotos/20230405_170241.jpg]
 

During efforts to decide the length of the cabnet.  
The bottom panel long dimension was set to 463mm. 

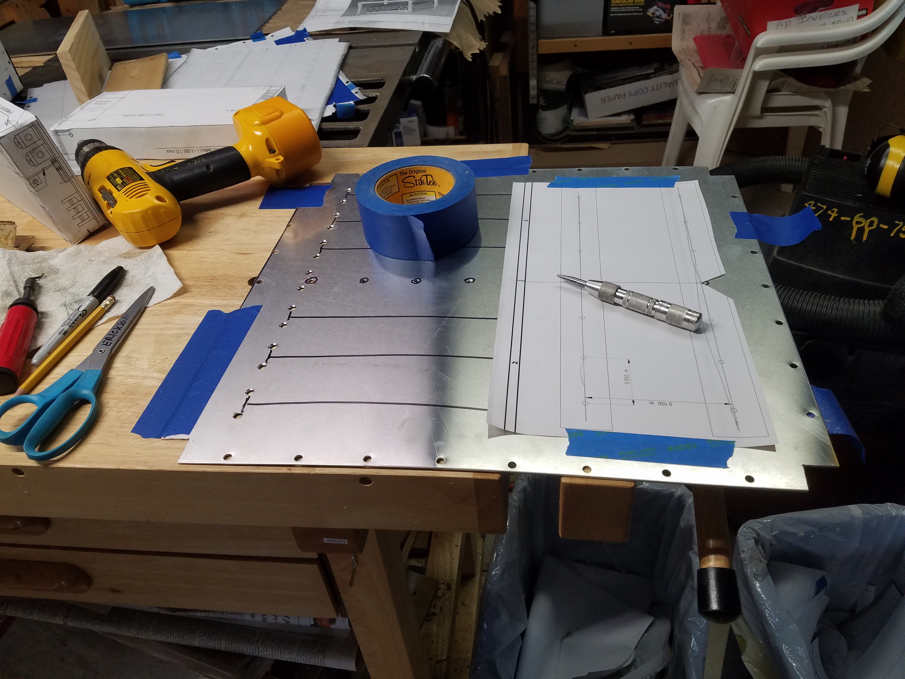
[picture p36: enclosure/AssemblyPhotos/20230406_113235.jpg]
  
Prepairing to center punch the front DIN rail holes

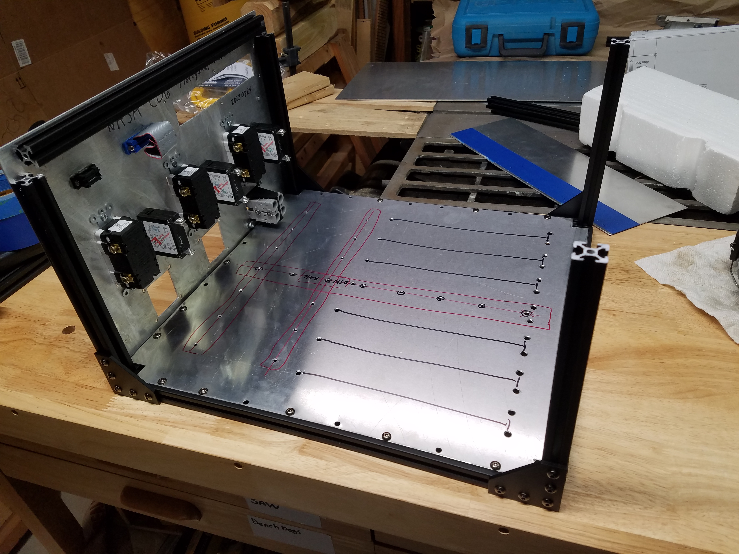
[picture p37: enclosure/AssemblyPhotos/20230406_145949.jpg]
  
After punching DIN rail holes.  Red outlines the proposed approximat location of the DIN rails.

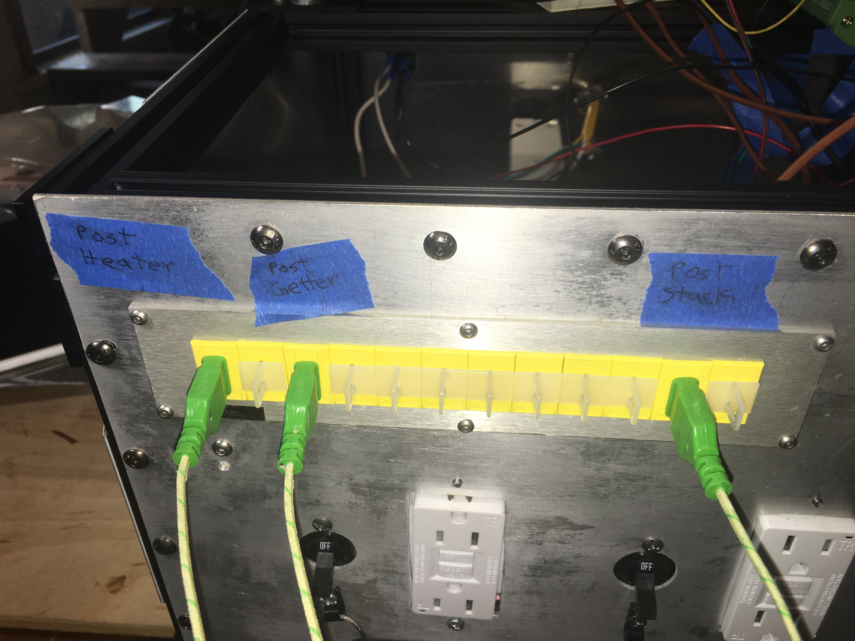
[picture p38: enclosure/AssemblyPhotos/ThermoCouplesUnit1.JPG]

Detail of the thermocouple jack panel.

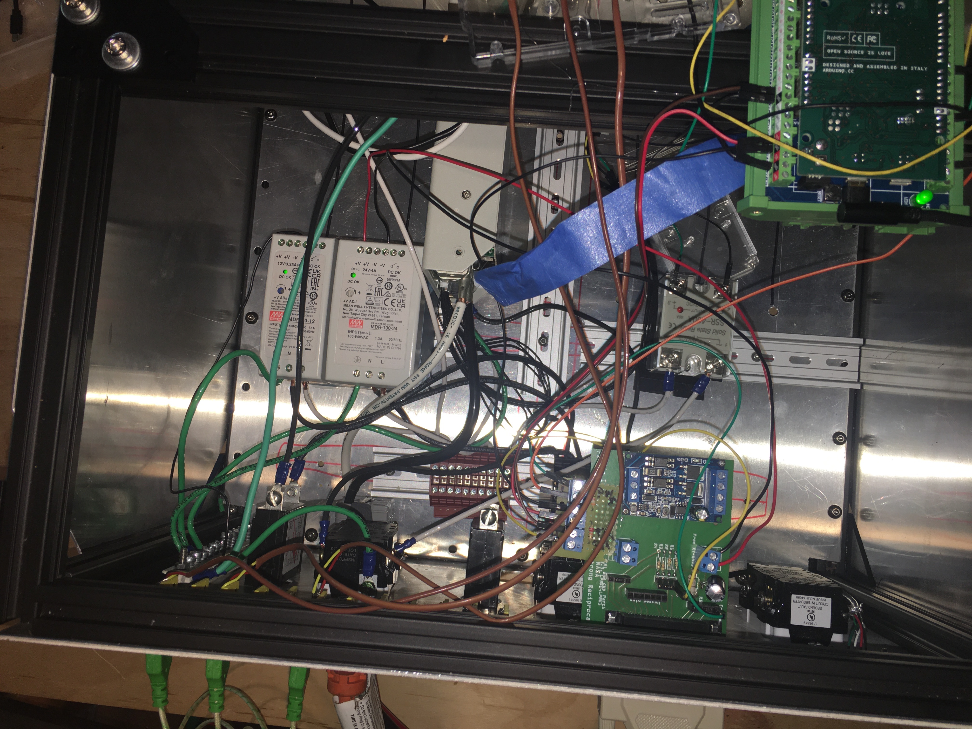
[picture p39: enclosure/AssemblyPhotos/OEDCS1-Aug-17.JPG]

Overhead view of OEDCS1-Aug-17.JPG

### Videos made during assembly

[20230405_164525.mp4](20230405_164525.mp4)

[20230405_165244.mp4](20230405_165244.mp4)

[20230405_165423.mp4](20230405_165423.mp4)

[20230405_224931.mp4](20230405_224931.mp4)

[20230407_164746.mp4](20230407_164746.mp4)

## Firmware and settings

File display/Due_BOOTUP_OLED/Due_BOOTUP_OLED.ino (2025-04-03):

#define PROG_NAME "Due_BOOTUP_OLED"
// Author: Forrest Lee Erickson
// Date: 20250402
// A PMD BootUp, Similar to Do Nothing but Serial Splash, LCD Test, LCD Splash, DFPlayer Test, DFPlayer Splash, BootButton Test for stuck key. Loop() has only non blocking code.
// https://github.com/PubInv/krake/issues/158
// Hardware: Control V1.2

// Customized this by changing these defines

#define VERSION " V0.0.1 "
#define MODEL_NAME "Model: Due_BOOTUP_OLED"
#define DEVICE_UNDER_TEST "SN: 00001"  //A Serial Number
#define LICENSE "GNU Affero General Public License, version 3 "
#define ORIGIN "LB"

#define BAUDRATE 115200  //Serial port

#include <Wire.h>

// Some PMD Hardware
// Pins for switches and LEDs and more
#define BOOT_BUTTON 0
//FLE const int LED_BUILTIN = 2;


void splashserial(void) {
  //Serial splash
  Serial.println(F("==================================="));
  Serial.print(PROG_NAME);
  Serial.println(VERSION);
  Serial.println(MODEL_NAME);
  Serial.println(DEVICE_UNDER_TEST);
  Serial.print(F("Compiled at: "));
  Serial.println(F(__DATE__ " " __TIME__));  //compile date that is used for a unique identifier
  Serial.println(LICENSE);
  Serial.println(F("==================================="));
  Serial.println();
}


// The Setup

void setup() {

  pinMode(LED_BUILTIN, OUTPUT);
  digitalWrite(LED_BUILTIN, HIGH);  //Make built in LED low at end of setup.

  Serial.begin(BAUDRATE);
  while (!Serial) {
    ;  // wait for serial port to connect. Needed for native USB
  }
  splashserial();

  Wire.begin();
  initOLED();
  splashOLED();
  digitalWrite(LED_BUILTIN, LOW);  //Make built in LED low at end of setup.
}
//end setup()

void loop() {

  //  wink();  // Heart beat aka activity indicator LED function.

}  //end loop()

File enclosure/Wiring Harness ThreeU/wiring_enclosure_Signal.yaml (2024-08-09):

#templates for generalized connectors
templates:
  - &template_stack
    type: Anderson Power SB50 SB
    subtype:  Dual
    pinlabels: [V+, V-, V+, V-]
  - &template_pressure
    type: '<a href="https://www.amazon.com/dp/B089YTG1SX/"> GX12-4 </a>'
    subtype: female
    pinlabels: [GND, VCC, SCL, SDA]
    notes: GX12 4 Pins Panel Metal Mount Circular Metal Aviation Connector Adapter Male Female Plug Socket with Waterproof Cap (5 Pcs)
    pn: Pressure Connector
    manufacturer: N/A
    mpn: GX12-4
    supplier: Amazon
    spn: '<a href="https://www.amazon.com/dp/B089YTG1SX/"> GX12-4 </a>'
    
  - &template_tc
    type: Molex KK 254
    subtype: female
    pinlabels: [GND, VCC, SCL, SDA]
    
  - &template_gnd
    type: Molex KK 254
    subtype: female
    pinlabels: [GND]
    
  - &template_heater
    type: Molex KK 254
    subtype: female
    pinlabels: [GND, L1, L2]
    
  - &template_led
    type: Molex KK 254
    subtype: female
    pinlabels: [GND, VCC]
    pn: CN2
    manufacturer: JST
    mpn: PHDR-24VS
    supplier: Digi-Key
    spn: 
    
  - &template_fan
    type: Molex KK 254
    subtype: female
    pinlabels: [GND, VCC, SCL, SDA]
    
  - &template_stack_wire
    gauge: 6.00 mm2
    length: 0.2
    colors: [RD,BK,RD,BK]
    category: bundle
    
  - &template_fan_wire
    gauge: 18 AWG
    length: 0.2
    colors: [RD,BK,RD,BK]
    category: bundle
    
  - &template_psu 
    type: PHDR-24VS
    subtype: female
    pincount: 24
    pinlabels: [VS+, VO+, VS-, VO-, POK, GND, PAR, VSET, EN-, GND, EN+, AUX, ACI, GND, VCI, GND, AUX, GND, SCL, SDA, AUX, GND, RX, TX]
    show_pincount: true
    pn: CN2
    manufacturer: JST
    mpn: PHDR-24VS
    supplier: Digi-Key
    spn: 455-1177-ND
    image:
      src: resources/PHDR-24VS.png
      caption: Power Supply Connector
      scale: width #(width height true/false) Expand image width to fill the available image cell space
      width:  200  # Expand image cell to this minimum width
      height: 100   # Expand image cell to this minimum height
      #scale: height # Expand image height to fill the available image cell space
      fixedsize: true #default value is false in this case
    
cables:   # dictionary of all used cables and wires
  W1:    # unique cable designator/name
    gauge: 6.0 mm2  # cable attributes (see below)
    # defaults to false; can auto-convert between mm2 and AWG and display the result when set to true
    show_equiv: true
     # <int/float> is assumed to be in meters unless <unit> is specified
                                # e.g. length: 2.5 -> assumed to be 2.5 m
                                # or   length: 2.5 ft -> "ft" is used as the unit
                                # Units are not converted during BOM generation;
                                # different units result in separate BOM entries.
    length: 0.5
    #color_code: IEC
    wirecount: 2
    category: bundle
    colors: [RD,BK]     # list of colors (see below)
    wirelabels: [V+,V-] # optional; one label for each wire
  W2:
    gauge: 0.25 mm2
    show_equiv: true
    length: 0.5
    color_code: IEC
    wirecount: 24
    category: bundle
  W3:
    gauge: 1 mm2
    show_equiv: true
    length: 0.5
    color_code: IEC
    wirecount: 3
    category: bundle
  W4:
    <<: *template_stack_wire
  W5:
    <<: *template_stack_wire
  W6:
    <<: *template_stack_wire
  
#PM - Panel Mount
#CN Connector, free hanging
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

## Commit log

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2023-03-15 Change, rotate, Anderson Connectors for over and under pins orentation each circuit.
    [frontpanel.FCStd]
2023-03-15 Fix errors on Anderson connector on some holes. Add AC recepticals.
    [frontpanel.FCStd]
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2023-03-16 Add dxf file. Make a PDF of the dxf file using LibreCAD.
    [frontpanel-frontpanelfrontpanel001.dxf, frontpanel.FCStd]
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2023-03-18 Create README.md
    FreeCAD screen capture showing images of some of the parts behind the "frontpanel". Note there appears to be an error on the holes for the Anderson front panel connector mount.
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2023-03-23 Fix size on Anderson Panel holder. Fix size on image of same.
    [frontpanel.FCStd]
2023-03-23 Move thermo couples to left side. Move DB25 and DB9 to right and in line with thermo couples.
    [frontpanel.FCStd]
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2023-03-24 Enlarge Opening and fix holes for Anderson Connector. Mark PDF as Version 1.2
    [frontpanel.FCStd]
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2023-03-27 Create a dxf file of the Rev1.2 front panel for quoting of fabrication.
    [frontpanel.FCStd, frontpanel_Rev1_2.dxf]
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2023-03-29 Added 3D models and additions for the 15" and 24" depth version of the cases
    [2020_profile.scad, aluminium_extrusion_plate_brackets.scad, customizable_aluminium_extrusion_plate_brackets.scad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]
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2023-04-02 added svg wiring diagram initial push, also added updated enclosure 15" depth with middle mounting plate
    [enclosure_15.scad, enclosure_15.stl]
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2023-04-05 Change width to 440mm. Move edge mounting holes to center of 20x20. Fix some techdrawing bugs.
    [frontpanel.FCStd]
2023-04-05 Updates to frontpanel for version 1.3 per issue number 59 and more. New fabrication files at version 1.3.
    [frontpanel.FCStd, frontpanel_Rev1_3.dxf]
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2023-07-28 Reorder objects on Frontpanel making the pad and the perimiter holes first.
    [frontpanel.FCStd]
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2023-07-28 Generate dxf and step for RearPanel and rename Part in frontpanel file.
    [RearPanel3.dxf, RearPanel3.step, frontpanel.FCStd]
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2023-07-30 Import Decora receptical cover image. Scale and place. Move one Anderson Bezel forward to see interference.
    [frontpanel.FCStd]
2023-07-31 Add a drawing with dimensions for the two horizontal DIN rails on the bottom panel as per the March 2023 controller version 1.
    [frontpanel.FCStd]
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2023-07-31 Regenerate DXF files for Bottom and Rear using TechDraw and then right click export.
    [BottomPlateV1.dxf, RearPanel3.dxf, frontpanel.FCStd]
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2023-07-31 After pressing the recaculate button. And Selecting the AutoDesk DXF export. This worked to export a DXF!
    [frontpanel.FCStd]
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2023-08-02 Select only rear panel visible to import to A2plus assembly work bench.
    [frontpanel.FCStd]
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2023-08-03 Enclosure rough manual placement with constraint errors.
    [ASSY_ODECOS_V2.FCStd, Extrusions_Simple.FCStd]
2023-08-03 Changes to the Assy Odecos V2 and add lots of parts that make up the enclosure design and references to same.
    [20X28CornerBracket.step, ASSY_ODECOS_V2.FCStd, Decora cover v5.step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]
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2023-08-07 Add a parts info list and parts list. They are useless as is.
    [ASSY_ODECOS_V2.FCStd]
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2023-08-09 Add IEC AC power. Scale and move Thermocouple. Move DB25 and DB9.
    [frontpanel.FCStd]
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2023-08-10 Add PDF drawing of PowerWerx SB1 PanelPlate. and STEP and STL files.
    [PanelPlate_SB-PartBodySB1.step, PanelPlate_SB-PartBodySB1.stl, PanelPlate_SB.FCStd]
2023-08-10 As printing SB1 from STL. Update NASA COG Plantpanel for two IEC recepticals.
    [PanelPlate_SB-PartBodySB1.step, PanelPlate_SB-PartBodySB1.stl, PanelPlate_SB.FCStd]
2023-08-10 Add PDF drawing of PowerWerx SB2 PanelPlate and STEP and STL files.
    [PanelPlate_SB-PartSB2BodySB2.step, PanelPlate_SB-PartSB2BodySB2.stl, PanelPlate_SB.FCStd]
2023-08-10 Change PlantPanel for single Anderson SB1 plate. Update dimensions on PDF of SB1.
    [PanelPlate_SB.FCStd]
2023-08-11 Add a FreeCad Drawing of thermocouple jack panel with size guesses. Add jack panel to PlantPanel.
    [JackPanel_MJP.FCStd]
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2023-08-16 Update README.md
    Add to Front Panel Parts List:
    ground bar
    Details on thermocouple jack panel, snap strips and Miniature connectors.
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2023-08-16 3" 1/4" from the top sepeartion of low voltage from high voltage adds in a C19 C20 cutout and keeps the junction box wire nuts
    [rear panel edit 1_3.dxf]
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2023-08-24 Flip the front panel around.
    [ASSY_ODECOS_V2.FCStd]
2023-08-30 Add footprints to KiCad board. Make simple Due and Ethernte boards for pullin into FreeCAD assembly and do so.
    [ASSY_ODECOS_V2.FCStd]
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2023-09-06 Add Controler Support to Assy ODECOS, Move PCB dimensions to correct layer.
    [ControllerSupportRT.FCStd]
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2023-10-18 Fix holes in flange. Fix flang height.
    [TwoU_Chassis.FCStd]
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2023-11-30 Update gitignore not to ignore FreeCAD files. Add the BigTree holes in pannel FreeCAD drawing.
    [BigTreeTechHolesInPanel.FCStd]
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2024-04-05 Add a rough up of a 3U and 18x15 inch enclosure chassis.
    [ThreeU_Chassis.FCStd]
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2024-06-21 Reduce chassi from 18" to 17" for clearance in rack.
    [ThreeU_Chassis.FCStd]
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2024-06-26 Add holes to chassis for front panel and rear panel and eventual top.
    [ThreeU_Assembly_SinglePower.FCStd, ThreeU_Chassis.FCStd]
2024-06-26 Fix 3UAssembly after adding holes broke constraints.
    [ThreeU_Assembly_SinglePower.FCStd]
2024-06-26 Fix rubber feet centering. Make unfolded drawing practice.
    [ThreeU_Chassis.FCStd]
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2024-06-28 On 3U chassis increase bend radius to material thickness. SendCutSend order form showed an error.
    [ThreeU_Chassis.FCStd]
2024-06-28 On 3U chassis set bend radius to 0.035 per vendor instruction. Place Controler V1.1 Mounting holes.
    [ThreeU_Chassis.FCStd]
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2024-06-30 Changed order of fold on chassis. This reports a DAG problem.
    [ThreeU_Chassis.FCStd]
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2024-07-01 Clone the front panel and add power siwtch, O2 on switch, O2 LED, 4 K thermocouple jacks, and Fan connector.
    [ThreeU_Chassis.FCStd]
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2024-07-01 Fix fold base objects per advise from Frothman.
    [ThreeU_Chassis.FCStd]
2024-07-01 Tweeks to chassi holes for DIN rail mounts. Tweek to power supply placement.
    [ThreeU_Chassis.FCStd]
2024-07-01 Commit before fixing Control board orentation.
    [ThreeU_Chassis.FCStd]
2024-07-01 Fixing Control board orentation.
    [ThreeU_Chassis.FCStd]
2024-07-01 Tweeking to chassis, reduce the slot count. Make flat power supply mounts slots.
    [ThreeU_Chassis.FCStd]
2024-07-01 Before trying to clear front panel hole errors when rack mount holes added.
    [ThreeU_Chassis.FCStd]
2024-07-01 Trying and failing to clear front panel hole errors when rack mount holes added.
    [ThreeU_Chassis.FCStd]
2024-07-02 Still trying and failing to clear front panel hole errors when rack mount holes added.
    [ThreeU_Chassis.FCStd]
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2024-07-04 Add a grounding hole to the rear panel. Try to add grouding hole to chassis. Update notes on Fand 3D model.
    [ThreeU_Chassis.FCStd]
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2024-07-08 Add a hole to front panel for C20 receptical. Delete old step file and add new one.
    [ThreeU_Chassis-BodyFrontPanelWithHoles20240703_1650.step, ThreeU_Chassis-BodyFrontPanelWithHoles20240708_1444.step, ThreeU_Chassis.FCStd]
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2024-07-16 Add drawings for 20" and 30" angle iron and a plant cage.
    [AngleIron20inch.FCStd, AngleIron30inch.FCStd, PlantCage.FCStd]
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2024-07-16 Change size on O2 hole in Plant Panel. Add plant panel to plant assembly.
    [PlantCage.FCStd, ThreeU_Chassis.FCStd]
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2024-07-16 Add back in the holes for I2C connector and Fan. Make a STEP file for Plant panel.
    [AssyPlantCage.FCStd, ThreeU_Chassis-BodyPlantPanelWithHoles20240716_1703.step, ThreeU_Chassis.FCStd]
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2024-08-09 Delete mech/enclosure/signal-desktop-keyring.gpg
    @LokiMetaSmith added this by mistake. this shouldn't have ever been in a git repo. not sure how it got in there.
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2024-09-09 Fix errors on Powerwerx PanelPlateSB1
    [ThreeU_Chassis.FCStd]
2024-09-09 Fix errors on Thermocouple panel mounts.
    [ThreeU_Chassis.FCStd]
2024-09-09 Fix missing horizontal contraint on C20 holes.
    [ThreeU_Chassis.FCStd]
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2024-09-25 Fix Panel Mount for SB50 width and height.
    [ThreeU_Chassis.FCStd]
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2024-09-26 Fix front panel anderson flang, fix plane panel anderson flang, fix O2 hole on plane panel.
    [ThreeU_Chassis.FCStd]
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2024-10-02 New STEP files for Front Panel and Plant Panel after fixing Issue 319.
    [ThreeU_Chassis-BodyFrontPanelWithHoles20241002.step, ThreeU_Chassis-BodyPlantPanelWithHoles20241002.step]
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2025-01-21 ThreeU_Chassis.FCStd Redraw the fold sketches of chassis. Fixes the eges of folds.
    [ThreeU_Chassis.FCStd]
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
